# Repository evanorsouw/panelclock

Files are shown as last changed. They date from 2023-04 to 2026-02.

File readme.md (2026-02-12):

# 1 Introduction

This project was the result of wanting to do something with those 64x64 RGB panels you see so often. 
The HUB75 interface that they use requires constant updating at a speed of (max) 30MHz.
I saw very clever solutions using Arduino and ESP boards but they lacked the ability to refresh
at a high enough frequency or at 8 bit color depth. I have always wanted to do something with an FPGA
and this is my first projects integrating the ICE40HX4K FPGA chip into a design.

Since I like clocks (as so many people) in all their shapes I decided create a clock from it.

> _This repository contains all files for the hardware (Kicad), FPGA (VHDL via IceCUBE2), software (C++/FreeRTOS/PlatformIO) and the mechanical stl files (design was made from Fusion360 but these are not in this archive).  
However much more documentation is needed not only for others, but also for myself as a reference later on._

It clock comes in 2 flavors, as a double panel in 128x64 landscape or portrait mode and as a single 64x64 panel.

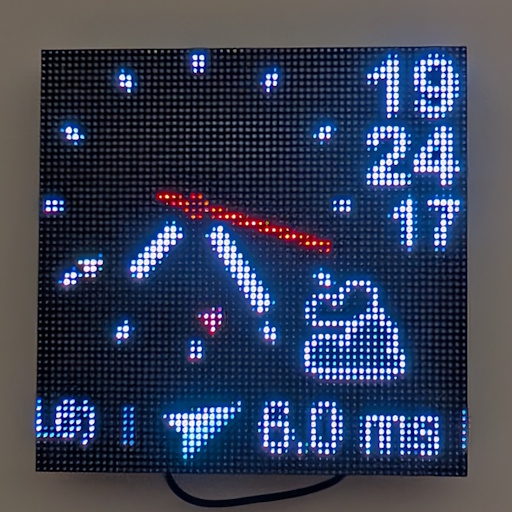
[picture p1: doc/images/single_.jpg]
single

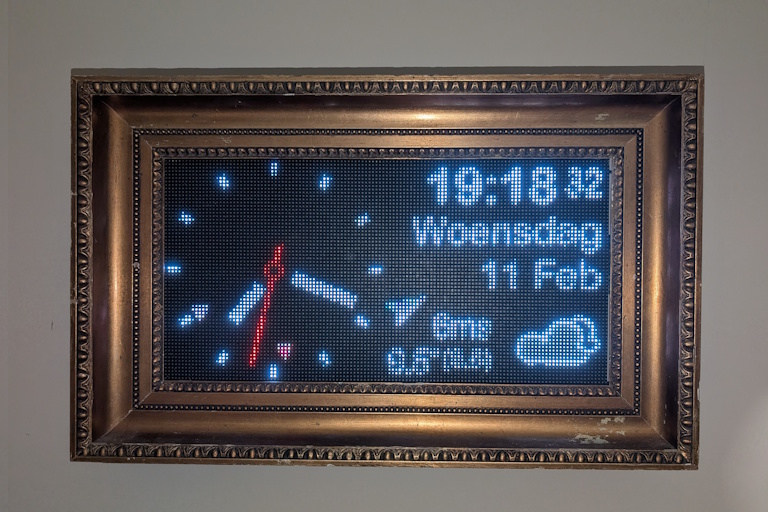
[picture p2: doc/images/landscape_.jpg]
landscape

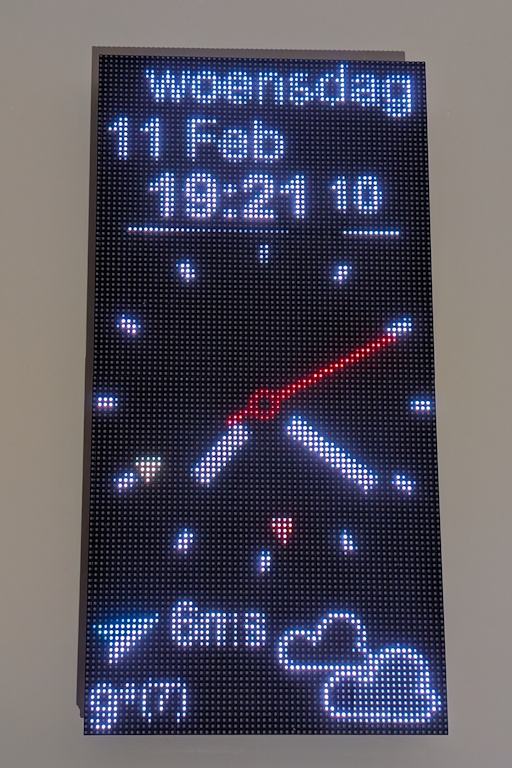
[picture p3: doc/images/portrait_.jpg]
portrait


# 1.1 History

The initial idea began somewhere 2019 with the purchase of a MAX1000 FPGA board. For this I created a small breakout board to 2 HUB75 connectors. The FPGA was used to do 25Hz rendering at 8bit color depth. The USB connector on the [MAX1000 board](https://duckduckgo.com/?t=ffab&q=google+max1000+trenz&ia=web) was used to push screen updates from the Linux system to the FPGA. The software was C# that I developed and tested on Windows in a simulation and run on Linux afterwards. This setup worked ok but required an external PC (NUC) running linux. You can still find this code in the `old` directory.

I wanted a compact stand-alone setup so in 2024 I started on designing a standalone system. Since at that time the bare MAX10 chip was not easily for sale for searching for an alternative I ran into the ICE40 FPGA. Less capable but more than enough for my purpose. Only real drawback was that internal FPGA memory was far less resulting in the need to add some external static RAM. 

Software wise there was a lot of trial-and-erroring and a lot of hurdles to get over. At the end it all worked nicely but it lacked unittests and the code is quite messy at places. Specifically getting the graphics rendering up to speed was challenging. Running bare metal, the very simple task of drawing 
antialised graphics took months to complete. The solution here was to have the ability to draw an antialised triangle and use that as basis for the rest. Text drawing was done using the brilliant [libschrift](https://github.com/tomolt/libschrift) library that allows me to render TTF fonts.

So in the end, now I know what I want and need I should rewrite much of the software and structurally add unittest...

# 2 Hardware

The hardware used in this project is relatively simple, with an ESP32 as main controller running the clock software and continuously pushing newly rendered images to the FPGA.
An ICE40 FPGA is used to refresh the images on 2 HUB75 connected displays.
Other than these 2 main components, the is a static 256KB RAM chip where the FPGA stores the received images (24KB each) for displaying, a simple USB based powersupply for 3v3 and 1v8, the well known CH340 chip for programming and downloading. There is also a MAX983657 amplifier on there but software wise it is not used yet. Most parts of this schematic are from standard application notes.

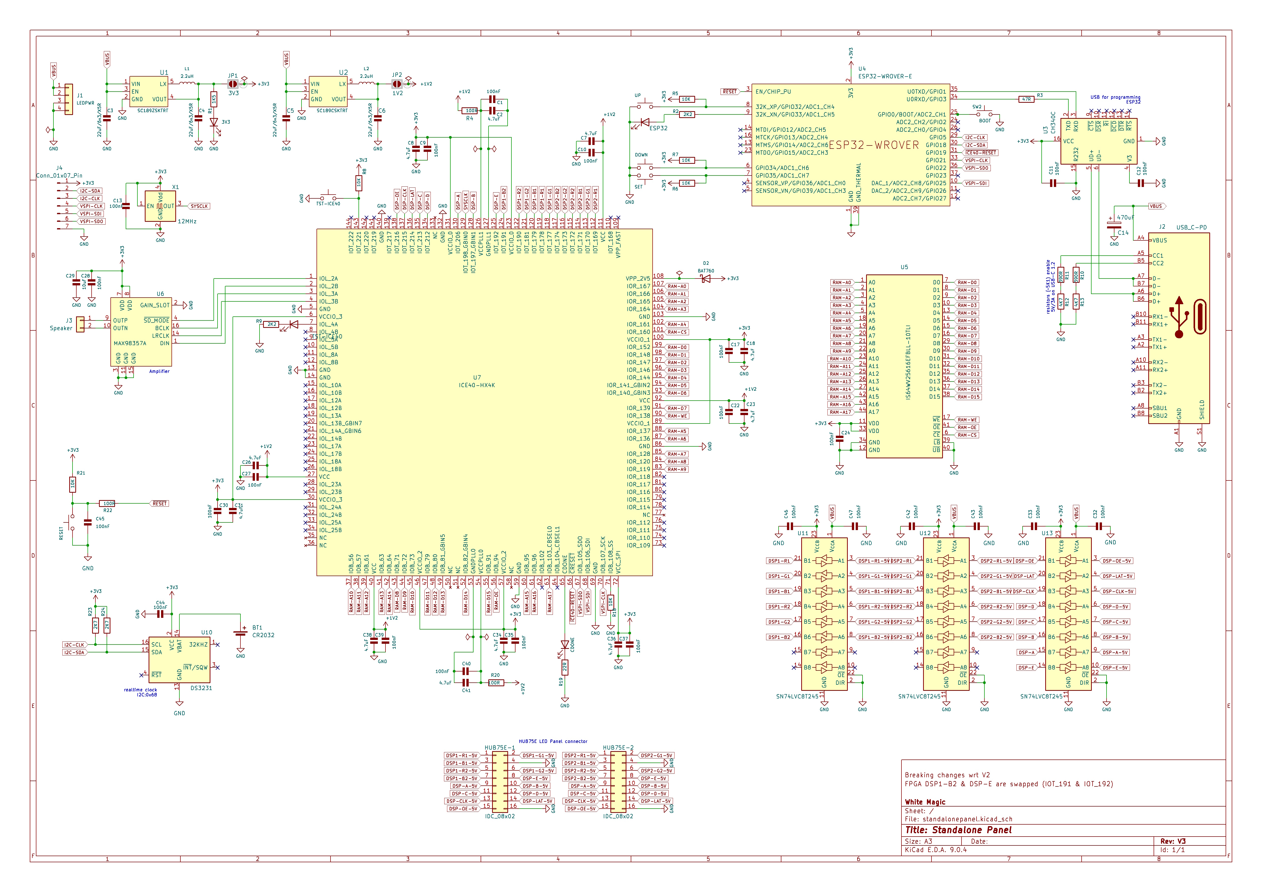
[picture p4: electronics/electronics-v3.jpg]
schematic


 The assembled 2-layer PCB looks like this; 
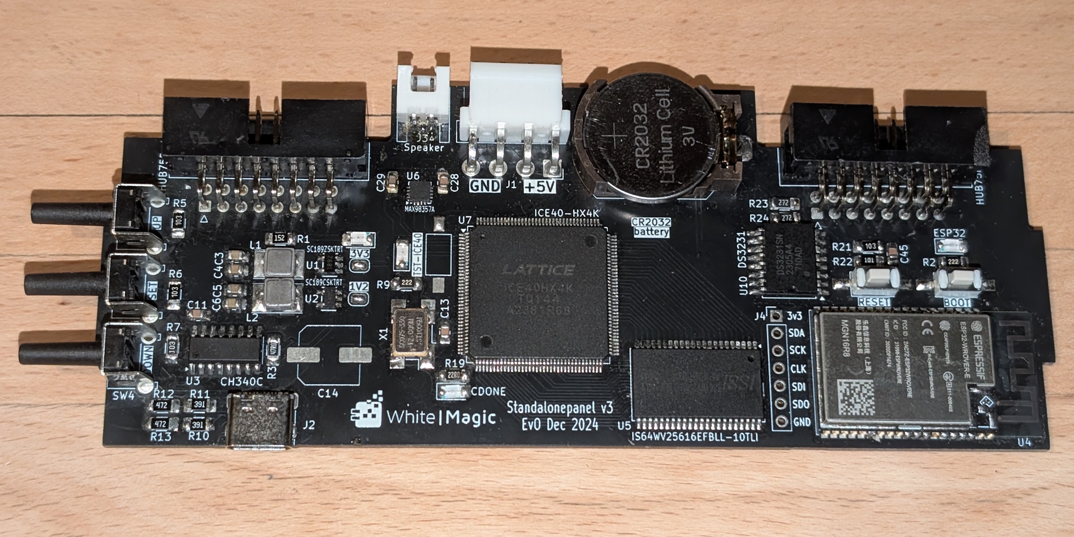
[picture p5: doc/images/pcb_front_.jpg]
pcb_front

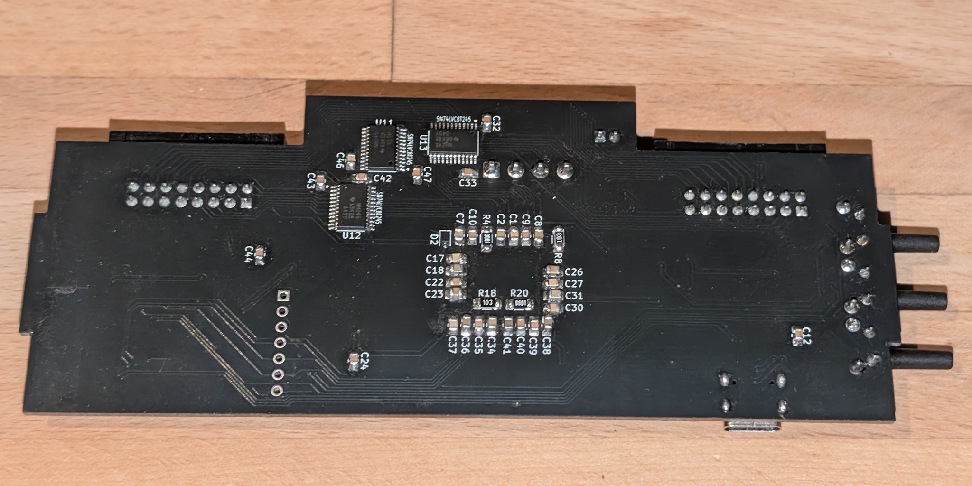
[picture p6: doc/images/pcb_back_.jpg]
pcb_back


# 3 Software

The software for the FPGA is VHDL compiled with the free (for personal use) [ICECube2 software](https://www.latticesemi.com/iCEcube2) from Lattice. 

The software for the ESP32 is developed using VisualCode and PlatformIO using FreeRTOS. The FPGA is configured via the ESP32 at startup via SPI. The ESP32 is setup to use A/B bootmode. When the software runs it will periodically (daily, weekly, monthly) check a configurable website if new software is available. If new software is found, it is installed and run. A special button combo during boot will revert the system back it fails.

The application uses 2 bitmaps that I toggle between. While 1 bitmap is being rendered, the other is sent to the FPGA. Since the ESP32 has 2 cores I typially use 1 core for rendering and the other for transferring the data. Some additional tasks run periodically like syncing with NTP and retrieving weather info.

The system has 3 buttons, `up`,`down` and `select` that are used for configuring the system. There are a number of configurable items for Wifi, NTP server, timezone etc. For weather information, [openweather](https://openweathermap.org/api) is used which requires you to request a free API key. This key also needs to be entered here together with your location. GUI-wise there is not much to configure the display is fixed but does display a variety of periodic animations, 5-minutes tick animations, expanding circles, game of life. 

A [usermanual](doc/usermanual.md) is found here.

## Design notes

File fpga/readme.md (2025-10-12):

# Programming the ICE40.

## Using my own Flash Programmer

mode com12 baud=115200 data=8 dtr=off stop=1 parity=n rts=off
copy /b ice40_Implmnt\sbt\outputs\bitmap\toplevel_bitmap.bin \\.\com12

## using Olimes 32u4 board;
-----------------------

1) have a Olimex 32U4 board programmed and connected via comport.
   determine comport (must be <10). if higher, then use device manager to change the comport
2) have the iCE40HX8K0-EVB board connected via 16pin flatcable.
   and powered via external jack to 5V.
4) from cmd prompt:
   winiceprog.exe -ICOMX -t
   => Manufacturer ID: 0x1C / Device ID: 0x7015
   this is the indication that the ICE40 board is found.
5) winiceprog -ICOM2 -v <binfile>
e.g.: WinICEProg.exe -ICOM2 -v ice40\ice40_Implmnt\sbt\outputs\bitmap\toplevel_bitmap.bin

Add to FPGA code:

- setcolor(r,g,b)
0x03,<R>,<G>,<B>

- setpixel(x,y,alpha) - use current color and blend pixel at x,y with existing pixel using <alpha>
0b10aaaaaa,<x>,<y>

- setnextpixel(alpha) - use current color and last position (x+1,y) and blend existing pixel using alpha then update current position to (x+1,y)
0b11aaaaaa 

the FPGA must get ability to read an RGB pixel value back from memory.
- writing a pixel takes 8 writes (each RGB bit need 1 read)
- reading a pixel also takes 8 writes

the alpha pixel blend must:
- read 24 pixel from memory 
- merge color using 6 bit alpha value:
  - calculate the color value for each RGB channel in the pixel:
    - clip(old * (63-alpha) + new * alpha, 255)
- write 24 pixel back to memory

performance:
- each read/write of a set of RGB pixels takes 2 clock cycles
- given 8 reads and 8 write leaves requires 16*x = 32 clock cycles.
- at 60MHz this leaves an ideal bandwith of ~1.877 million pixels, or 228 full 128x64 screens

using above techniques we can render a screen that has say 30% filling:
- worst case: 128 * 64 * 30% * 3 (setpixel) = 7372 bytes (@115200 baud = 0.64 sec)
- with 90% scanlines: (128 * 64 * 0.3) * 10% * 3 + (128 * 64 * 0.3) * 90% * 1 = 2949 (@115200 baud = 0.256 sec)

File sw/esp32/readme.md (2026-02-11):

# Board config

Because I used a ESP32-WROVER-E 16Mb (and with PSRAM) module on a custom PCB, I created a custom board configuration.
I copied an existing board file using a wrover module and modified it.

This board configuration, named `standalone-panel.json` is stored in the `boards`  directory of the project.

From the `platform.ini` you can refer to it by using the filename without json extension.

There were the links I used:
- <https://docs.platformio.org/en/stable/platforms/creating_board.html>
- <https://docs.platformio.org/en/latest/platforms/espressif32.html>

# Storing FPGA bitstream on ESP32 filesystem

SPIFFS is the concept used to stored data file in ESP32 flash memory. 
The ESP32-WROVER-E has 16MB of flash. you have to create a custom partition table to set space aside for the filesystem.

The gist is as follows:
- create custom partition table, e.g. `partitions.csv` and store it in the root of the project.
- copy the contents of an existing partition file and add the following line:
  - `storage,  data, spiffs,  ,        2M` to reserve 2Mb for the data partition.
- in `platform.ini` add an entry `board_build.partitions = partitions.csv`
- Add the following line to the file `CMakeFile.txt`:
  - `spiffs_create_partition_image(spiffs data)` 
- create the directory `data` in the root of yout project
- place the file you want to have available on the ESP32 in the `data` directory.
- run `menuconfig` and make the following change
  - in the partitions section select `Custom partition table CSV` and name it `partitions.csv`
- Now from platformio, select `Build Filesystem Image` and `Upload Filesystem Image`
  or  or even simpler, just use `Upload Filesystem Image`.

There were the links I used:
- https://community.platformio.org/t/unable-to-build-and-upload-spiffs-filesystem-image-with-framework-esp-idf/17820

# 2 Updating software

1. Build the software  
When all is fine, a firmware package `firmware.bin` is copied to the `sw\esp32\data` directory, along with a new manifest that contains a newer version number. 
2. Upload the files `firmware.bin` and `manifest.bin` to the web location that is monitored by the panelclock (default configuration: `whitemagic.it/panelclock`)
3. The panelclock will autmomatically pick it up next time it checks. By default the interval setting `Update` setting  is set to `weekly`. During development this can be changed to `minutely`.

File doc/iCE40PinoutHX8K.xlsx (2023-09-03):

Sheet: Pinout
iCE40 Pinout HX8K
Ball Function | Pin Type | Bank | (BG121) 121-Ball caBGA Ball Number | (CB132) 132-Ball csBGA Ball Number | (CM225) 225-Ball ucBGA Ball Number | (CT256) 256-Ball caBGA Ball Number
IOL_1A | DPIO | 3 | - | - | C2 | E4
IOL_1B | DPIO | 3 | - | - | B1 | B2
IOL_2A | DPIO | 3 | B1 | B1 | E4 | F5
IOL_2B | DPIO | 3 | B2 | C1 | D4 | B1
IOL_3A | DPIO | 3 | - | - | E3 | C1
IOL_3B | DPIO | 3 | - | - | C1 | C2
IOL_4A | DPIO | 3 | C4 | C3 | E5 | F4
IOL_4B | DPIO | 3 | C3 | D3 | D3 | D2
IOL_5A | DPIO | 3 | C2 | D1 | E6 | G5
IOL_5B | DPIO | 3 | C1 | E1 | D1 | D1
IOL_6A | DPIO | 3 | - | - | D2 | G4
IOL_6B | DPIO | 3 | - | - | E2 | E3
IOL_7A | DPIO | 3 | - | - | - | H5
IOL_7B | DPIO | 3 | - | - | - | E2
IOL_8A | DPIO | 3 | E1 | D4 | F5 | G3
IOL_8B | DPIO | 3 | D1 | E4 | F4 | F3
IOL_9A | DPIO | 3 | D2 | F4 | F3 | H3
IOL_9B | DPIO | 3 | D3 | F3 | F2 | F2
IOL_10A | DPIO | 3 | E2 | H4 | G2 | H6
IOL_10B | DPIO | 3 | E3 | G4 | F1 | F1
IOL_11A | DPIO | 3 | - | - | G3 | H4
IOL_11B | DPIO | 3 | - | - | G1 | G2
IOL_12A | DPIO | 3 | F1 | J3 | G5 | J4
IOL_12B | DPIO | 3 | F2 | J1 | H2 | H2
IOL_13A | DPIO | 3 | F4 | G3 | H6 | J5
IOL_13B_GBIN7 | GBIN | 3 | F3 | G1 | G4 | G1
IOL_14A_GBIN6 | GBIN | 3 | G1 | H1 | H5 | J3
IOL_14B | DPIO | 3 | G2 | H3 | H1 | H1
IOL_15A | DPIO | 3 | - | - | H3 | J2
IOL_15B | DPIO | 3 | - | - | J3 | J1
IOL_16A | DPIO | 3 | - | - | H4 | K1
IOL_16B | DPIO | 3 | - | - | J1 | K3
IOL_17A | DPIO | 3 | G3 | - | J5 | L4
IOL_17B | DPIO | 3 | H3 | - | J2 | L1
IOL_18A | DPIO | 3 | H1 | K3 | J4 | K4
IOL_18B | DPIO | 3 | H2 | K4 | K1 | M1
IOL_19A | DPIO | 3 | - | - | - | L6
IOL_19B | DPIO | 3 | - | - | - | L3
IOL_20A | DPIO | 3 | - | - | K3 | K5
IOL_20B | DPIO | 3 | - | - | L1 | M2
IOL_21A | DPIO | 3 | - | - | - | L7
IOL_21B | DPIO | 3 | - | - | - | N2
IOL_22A | DPIO | 3 | - | - | L3 | M6
IOL_22B | DPIO | 3 | - | - | M1 | M3
IOL_23A | DPIO | 3 | J1 | L1 | K5 | L5
IOL_23B | DPIO | 3 | K1 | M1 | M2 | N3
IOL_24A | DPIO | 3 | - | - | N2 | P1
IOL_24B | DPIO | 3 | - | - | M3 | M4
IOL_25A | DPIO | 3 | K2 | N1 | P1 | P2
IOL_25B | DPIO | 3 | J2 | P1 | K4 | M5
IOL_26A | DPIO | 3 | - | - | M4 | R1
IOL_26B | DPIO | 3 | - | - | L4 | N4
IOB_52 | PIO | 2 | - | - | N3 | N6
IOB_53 | PIO | 2 | - | - | P2 | T1
IOB_54 | PIO | 2 | - | - | N4 | P4
IOB_55 | PIO | 2 | - | - | R1 | R2
IOB_56 | PIO | 2 | L1 | P2 | L5 | N5
IOB_57 | PIO | 2 | J3 | - | R2 | T2
IOB_58 | PIO | 2 | - | - | - | P5
IOB_59 | PIO | 2 | - | P3 | - | R3
IOB_60 | PIO | 2 | - | - | M5 | R5
IOB_61 | PIO | 2 | L2 | - | R3 | T3
IOB_62 | PIO | 2 | - | - | L6 | -
IOB_63 | PIO | 2 | K3 | M4 | P4 | R4
IOB_64 | PIO | 2 | J4 | M3 | M6 | M7
IOB_65 | PIO | 2 | - | - | R4 | -
IOB_66 | PIO | 2 | - | - | - | N7
IOB_67 | PIO | 2 | - | - | N5 | P6
IOB_68 | PIO | 2 | - | - | - | M8
IOB_69 | PIO | 2 | - | - | P5 | T5
IOB_71 | PIO | 2 | L3 | L5 | R5 | R6
IOB_72 | PIO | 2 | L4 | L4 | L7 | P8
IOB_73 | PIO | 2 | K4 | P4 | N6 | T6
IOB_74 | PIO | 2 | - | P5 | - | L9
IOB_75 | PIO | 2 | - | - | M7 | T7
IOB_76 | PIO | 2 | - | - | - | T8
IOB_77 | PIO | 2 | - | M6 | P6 | P7
IOB_78 | PIO | 2 | J5 | L6 | M8 | N9
IOB_79 | PIO | 2 | K5 | M7 | R6 | T9
IOB_80 | PIO | 2 | - | - | - | M9
IOB_81_GBIN5 | GBIN | 2 | L5 | P7 | N7 | R9
IOB_82_GBIN4 | GBIN | 2 | K6 | P8 | L9 | K9
IOB_83 | PIO | 2 | - | - | P7 | P9
GNDPLL0 | GNDPLL | GNDPLL | L6 | L7 | N8 | N8
VCCPLL0 | VCCPLL | VCCPLL | J6 | M8 | L8 | L8
IOB_84 | PIO | 2 | - | - | P8 | R10
IOB_85 | PIO | 2 | - | - | M9 | L10
IOB_86 | PIO | 2 | J7 | - | N9 | P10
IOB_87 | PIO | 2 | H7 | L8 | K9 | N10
IOB_88 | PIO | 2 | - | - | R9 | T10
IOB_89 | PIO | 2 | K7 | P9 | L10 | T11
IOB_90 | PIO | 2 | - | - | P9 | -
IOB_91 | PIO | 2 | J8 | M9 | N10 | T15
IOB_92 | PIO | 2 | - | - | P10 | T14
IOB_93 | PIO | 2 | - | - | - | M11
IOB_94 | PIO | 2 | L7 | - | R10 | T13
IOB_96 | PIO | 2 | - | - | P11 | -
IOB_98 | PIO | 2 | - | - | R11 | N12
IOB_99 | PIO | 2 | - | - | - | L11
IOB_100 | PIO | 2 | - | - | P13 | T16
IOB_101 | PIO | 2 | - | - | - | M12
IOB_102 | PIO | 2 | - | - | R12 | R16
IOB_103_CBSEL0 | PIO | 2 | L8 | L9 | K11 | K11
IOB_104_CBSEL1 | PIO | 2 | H9 | P10 | P12 | P13
CDONE | CONFIG | 2 | K8 | M10 | M10 | M10
CRESET_B | CONFIG | 2 | L9 | L10 | N11 | N11
IOB_105_SDO | SPI | SPI | K9 | M11 | M11 | P12
IOB_106_SDI | SPI | SPI | J9 | P11 | L11 | P11
IOB_107_SCK | SPI | SPI | L10 | P12 | N12 | R11
IOB_108_SS | SPI | SPI | K10 | P13 | M12 | R12
VCC_SPI | SPI | SPI | L11 | L11 | N13 | N13
IOR_109 | PIO | 1 | - | M12 | R15 | R14
IOR_110 | PIO | 1 | - | P14 | P15 | R15
IOR_111 | PIO | 1 | - | L12 | R14 | P14
IOR_112 | PIO | 1 | - | N14 | P14 | P15
NC | NC | NC | - | M14 | N14 | N14
IOR_113 | PIO | 1 | - | - | M15 | P16
IOR_114 | PIO | 1 | J11 | L14 | L12 | M13
IOR_115 | PIO | 1 | K11 | K12 | M13 | M14
IOR_116 | PIO | 1 | H10 | K11 | K12 | L12
IOR_117 | PIO | 1 | J10 | K14 | K13 | N16
IOR_118 | PIO | 1 | G8 | J12 | J10 | L13
IOR_119 | PIO | 1 | H11 | J11 | L13 | L14
IOR_120 | PIO | 1 | G10 | H12 | J12 | K12
IOR_121 | PIO | 1 | - | - | L14 | M16
IOR_122 | PIO | 1 | - | - | - | J10
IOR_123 | PIO | 1 | - | - | M14 | M15
IOR_125 | PIO | 1 | - | - | K15 | -
IOR_126 | PIO | 1 | - | - | - | J11
IOR_127 | PIO | 1 | - | - | - | L16
IOR_128 | PIO | 1 | G9 | H11 | J11 | K13
IOR_129 | PIO | 1 | G11 | G12 | J13 | K14
IOR_130 | PIO | 1 | - | - | - | J15
IOR_131 | PIO | 1 | - | - | K14 | K15
IOR_133 | PIO | 1 | - | - | J15 | K16
IOR_134 | PIO | 1 | - | - | - | J14
IOR_135 | PIO | 1 | - | - | J14 | -
IOR_136 | PIO | 1 | F10 | G11 | H11 | J12
IOR_137 | PIO | 1 | F9 | F12 | H14 | J13
IOR_138 | PIO | 1 | - | - | H13 | J16
IOR_139 | PIO | 1 | - | - | - | H13
IOR_140_GBIN3 | GBIN | 1 | F11 | F14 | H12 | H11
IOR_141_GBIN2 | GBIN | 1 | E10 | G14 | G13 | H16
IOR_142 | PIO | 1 | - | - | - | H14
IOR_143 | PIO | 1 | - | - | G15 | G16
IOR_144 | PIO | 1 | E9 | F11 | G11 | H12
IOR_145 | PIO | 1 | - | - | G14 | G15
IOR_146 | PIO | 1 | E8 | E11 | G10 | G10
IOR_147 | PIO | 1 | D9 | E12 | F14 | F16
IOR_148 | PIO | 1 | E11 | E14 | G12 | G11
IOR_149 | PIO | 1 | - | - | F15 | F15
IOR_150 | PIO | 1 | - | - | - | G14
IOR_151 | PIO | 1 | - | - | F13 | E16
IOR_152 | PIO | 1 | D11 | D14 | F12 | G13
IOR_153 | PIO | 1 | - | - | E14 | D16
IOR_154 | PIO | 1 | D10 | C14 | F11 | G12
IOR_155 | PIO | 1 | - | - | D14 | F14
IOR_156 | PIO | 1 | - | - | - | F12
IOR_157 | PIO | 1 | - | - | - | D15
IOR_158 | PIO | 1 | - | - | - | F11
IOR_159 | PIO | 1 | - | - | D15 | -
IOR_160 | PIO | 1 | C11 | D12 | D13 | E14
IOR_161 | PIO | 1 | B11 | B14 | E13 | C16
IOR_162 | PIO | 1 | - | - | - | F13
IOR_165 | PIO | 1 | - | - | C14 | B16
IOR_166 | PIO | 1 | - | - | - | E13
IOR_167 | PIO | 1 | - | - | B15 | D14
VPP_2V5 | VPP | VPP | C10 | A14 | E12 | E12
VPP_FAST | VPP | VPP | B10 | A13 | D12 | D12
IOT_168 | PIO | 0 | A11 | - | B14 | C14
IOT_169 | PIO | 0 | - | - | A15 | B15
IOT_170 | PIO | 0 | A10 | A12 | C12 | D13
IOT_171 | PIO | 0 | - | - | C13 | B14
IOT_172 | PIO | 0 | C9 | C12 | E11 | C12
IOT_173 | PIO | 0 | - | - | - | E11
IOT_174 | PIO | 0 | B9 | C11 | D11 | C13
IOT_176 | PIO | 0 | - | - | B13 | A16
IOT_177 | PIO | 0 | B8 | D10 | E10 | A15
IOT_178 | PIO | 0 | A9 | D11 | D9 | B13
IOT_179 | PIO | 0 | C8 | A11 | E9 | E10
IOT_180 | PIO | 0 | - | - | B12 | C11
IOT_181 | PIO | 0 | D7 | A10 | D10 | D11
IOT_182 | PIO | 0 | - | - | C11 | B12
IOT_183 | PIO | 0 | - | - | - | B10
IOT_184 | PIO | 0 | - | - | A11 | B11
IOT_185 | PIO | 0 | - | - | B11 | C10
IOT_186 | PIO | 0 | - | C10 | - | A10
IOT_187 | PIO | 0 | - | - | B10 | A11
IOT_188 | PIO | 0 | - | D9 | - | -
IOT_189 | PIO | 0 | - | - | A10 | -
IOT_190 | PIO | 0 | A8 | C9 | F9 | D10
IOT_191 | PIO | 0 | C7 | - | C10 | C9
IOT_192 | PIO | 0 | A7 | - | B8 | E9
IOT_193 | PIO | 0 | - | - | C8 | D9
IOT_194 | PIO | 0 | - | - | A9 | A9
IOT_195 | PIO | 0 | - | - | B9 | -
VCCPLL1 | VCCPLL | VCCPLL | C6 | C8 | E8 | E8
GNDPLL1 | GNDPLL | GNDPLL | C5 | D8 | E7 | E7
IOT_196 | PIO | 0 | - | - | A8 | F9
IOT_197_GBIN1 | GBIN | 0 | B7 | A7 | C9 | C8
IOT_198_GBIN0 | GBIN | 0 | B6 | A6 | D8 | F7
IOT_199 | PIO | 0 | - | - | - | B9
IOT_200 | PIO | 0 | - | C7 | - | D8
IOT_201 | PIO | 0 | - | - | B7 | -
IOT_202 | PIO | 0 | - | D7 | - | -
IOT_203 | PIO | 0 | - | - | C6 | B8
IOT_205 | PIO | 0 | - | - | A7 | A7
IOT_206 | PIO | 0 | A6 | C6 | C7 | C7
IOT_207 | PIO | 0 | A5 | D6 | A6 | B7
IOT_208 | PIO | 0 | B5 | A5 | D7 | B6
IOT_209 | PIO | 0 | - | - | B6 | C6
IOT_210 | PIO | 0 | - | - | - | D7
IOT_211 | PIO | 0 | A4 | D5 | D6 | A6
IOT_212 | PIO | 0 | D5 | C5 | F7 | D6
IOT_213 | PIO | 0 | - | - | - | A5
IOT_214 | PIO | 0 | - | - | B5 | B5
IOT_215 | PIO | 0 | - | - | - | E6
IOT_216 | PIO | 0 | - | - | A5 | B4
GND | GND | GND | - | A9 | A12 | A12
IOT_218 | PIO | 0 | - | - | B4 | A2
GND | GND | GND | - | F1 | A4 | A4
IOT_219 | PIO | 0 | B4 | A4 | C5 | D5
IOT_220 | PIO | 0 | - | - | B3 | A1
GND | GND | GND | - | F7 | E15 | E15
IOT_221 | PIO | 0 | B3 | C4 | D5 | C5
GND | GND | GND | E5 | G7 | G7 | G7
IOT_222 | PIO | 0 | A2 | A3 | A2 | C4
GND | GND | GND | E6 | G8 | G8 | G8
IOT_223 | PIO | 0 | A3 | A2 | C4 | B3
GND | GND | GND | E7 | G9 | G9 | G9
GND | GND | GND | F5 | H6 | H7 | H7
GND | GND | GND | F6 | H7 | H8 | H8
IOT_224 | PIO | 0 | - | - | B2 | D4
GND | GND | GND | F7 | H8 | H9 | H9
IOT_225 | PIO | 0 | A1 | A1 | C3 | E5
GND | GND | GND | G5 | J14 | J7 | J7
IOT_226 | PIO | 0 | - | - | A1 | D3
GND | GND | GND | G6 | J8 | J8 | J8
IOT_227 | PIO | 0 | - | - | - | C3
GND | GND | GND | G7 | L3 | J9 | J9
GND | GND | GND | - | P6 | K2 | K2
GND | GND | GND | H5 | - | K7 | K7
GND | GND | GND | - | - | L15 | L15
GND | GND | GND | - | - | R7 | R7
GND | GND | GND | - | - | - | T12
GND | GND | GND | - | - | - | T4
VCC | VCC | VCC | - | F8 | A14 | A14
VCC | VCC | VCC | D8 | G6 | F10 | F10
VCC | VCC | VCC | D4 | H9 | F6 | F6
VCC | VCC | VCC | - | J4 | H15 | K10
VCC | VCC | VCC | H8 | J7 | K10 | K6
VCC | VCC | VCC | H4 | - | K6 | L2
VCC | VCC | VCC | - | - | L2 | -
VCC | VCC | VCC | - | - | R8 | -
VCCIO_0 | VCCIO | VCCIO | - | A8 | A13 | A13
VCCIO_0 | VCCIO | VCCIO | - | F6 | A3 | A3
VCCIO_0 | VCCIO | VCCIO | D6 | - | F8 | A8
VCCIO_0 | VCCIO | VCCIO | - | - | - | F8
VCCIO_1 | VCCIO | VCCIO | - | F9 | C15 | C15
VCCIO_1 | VCCIO | VCCIO | F8 | H14 | H10 | H10
VCCIO_1 | VCCIO | VCCIO | - | - | N15 | H15
VCCIO_1 | VCCIO | VCCIO | - | - | - | N15
VCCIO_2 | VCCIO | VCCIO | H6 | J9 | K8 | K8
VCCIO_2 | VCCIO | VCCIO | - | M5 | P3 | P3
VCCIO_2 | VCCIO | VCCIO | - | - | R13 | R13
VCCIO_2 | VCCIO | VCCIO | - | - | - | R8
VCCIO_3 | VCCIO | VCCIO | - | E3 | E1 | E1
VCCIO_3 | VCCIO | VCCIO | E4 | J6 | G6 | G6
VCCIO_3 | VCCIO | VCCIO | G4 | K1 | J6 | J6
VCCIO_3 | VCCIO | VCCIO | - | - | N1 | N1

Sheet: Revision History
Version | Date | Description
3.1 | 2017/02/05 | change name from "CM121" to "BG121" for "121-Ball caBGA"
3.0 | 2017/01/18 | add CM121(new 9x9 mm package ucBGA121),Revision "iCE40HX08.pkt 1.1"
2.1 | 2013-06-13 | Included package ordering code.
2.0 | 2013-03-13 | Updated table format to include all packages
1.1 | 10/3/2012 | Changed name from "CT256" to "256 ball caBGA"
1.0 | 2012-03-22 | Production Release Updated Notes in Pinout tab.
0.9 | 2011-09-01 | Preliminary

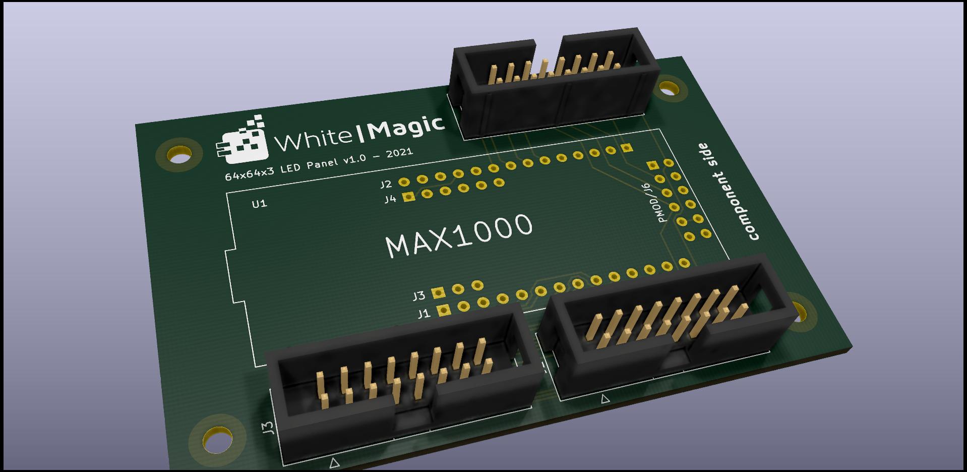
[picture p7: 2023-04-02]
electronics/kicad/max1000breakout/max1000breakout-v1.0.jpg

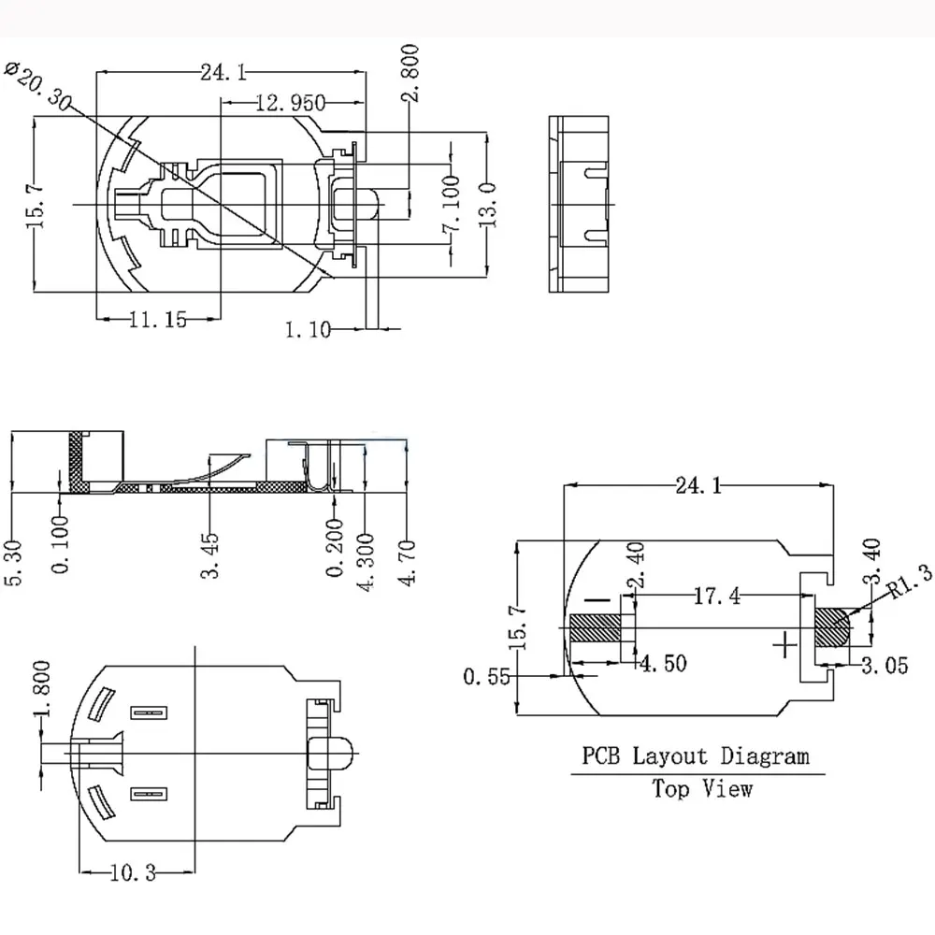
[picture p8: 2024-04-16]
doc/datasheet/batteryclip-2032.webp

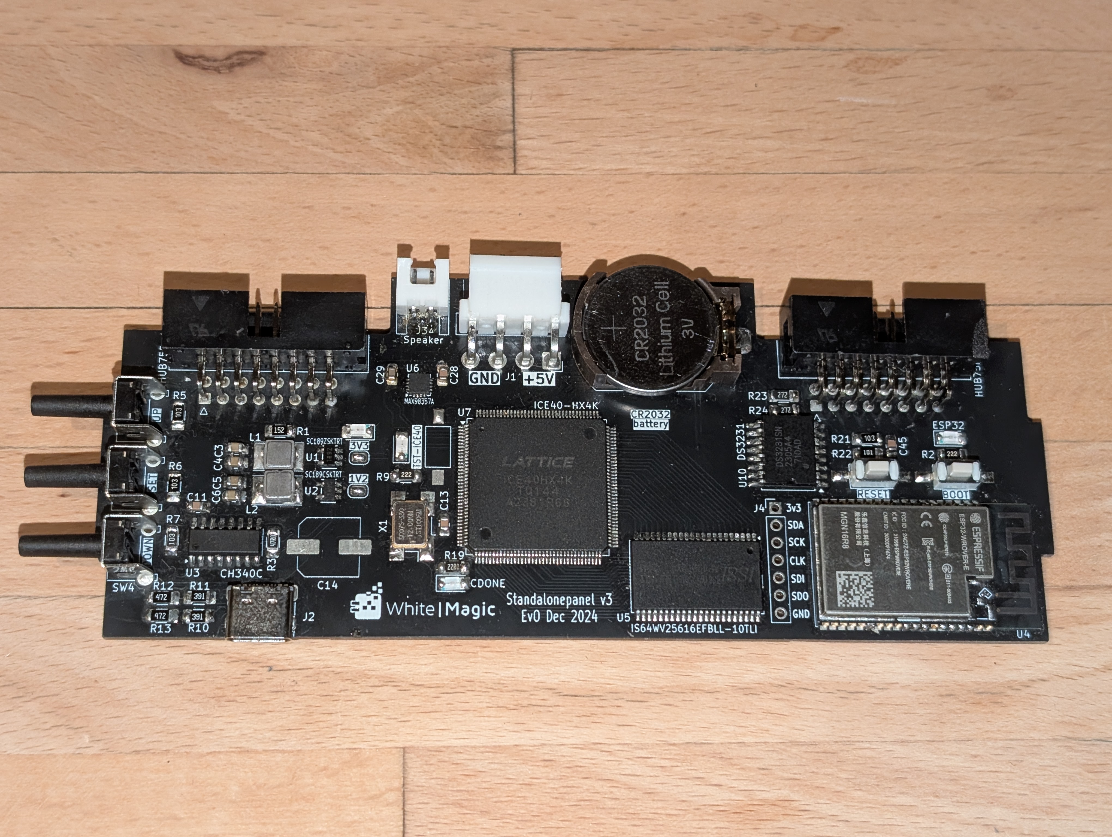
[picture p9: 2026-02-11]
doc/images/pcb_front.jpg

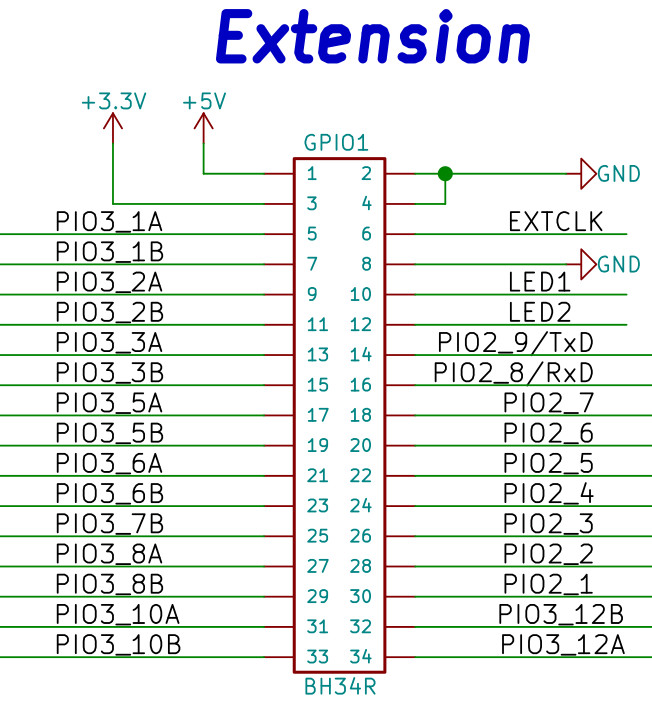
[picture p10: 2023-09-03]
doc/ICE40BUS.jpg

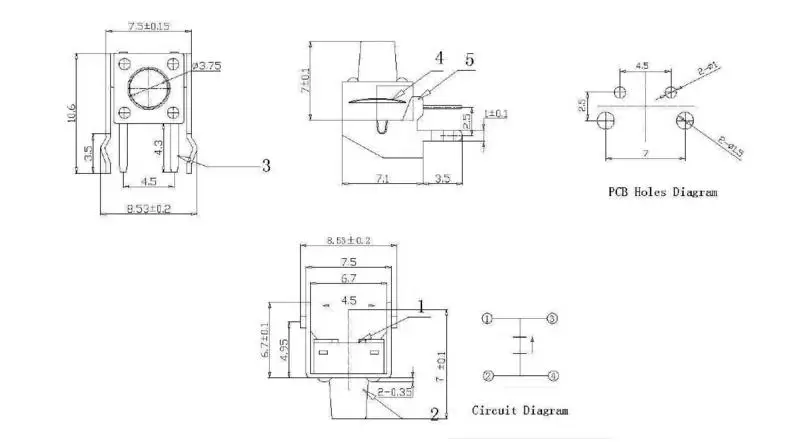
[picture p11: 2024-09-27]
doc/datasheet/100Pcs-Tact-Switch-6-6-9mm-Horizontal-with-Bracket-Tactile-Push-Button-Switches-6x6x9mm-Micro-Switch.jpg_.webp

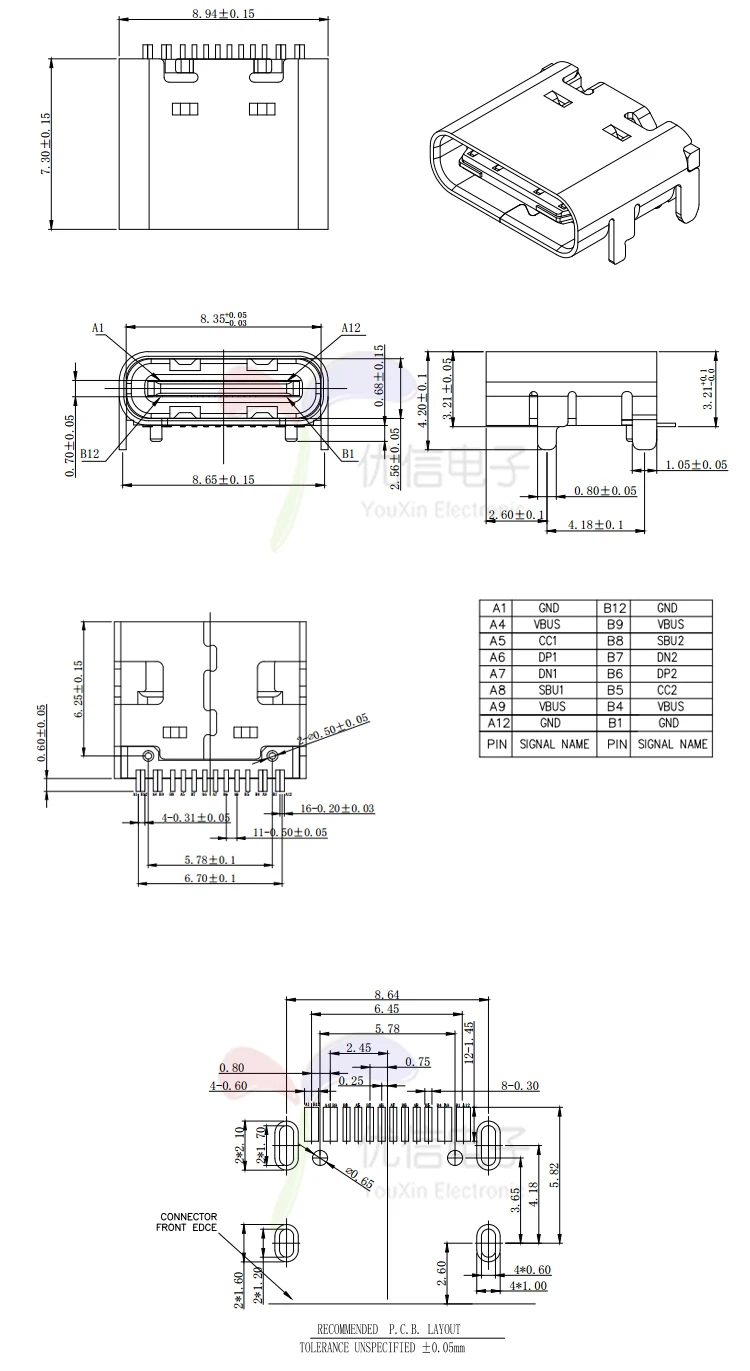
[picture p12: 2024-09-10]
doc/usb-c-connector-info.webp

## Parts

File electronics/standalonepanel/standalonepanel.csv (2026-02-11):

Source: | D:\projects\fpgaclock\electronics\kicad\standalonepanel\standalonepanel.kicad_sch
Date: | 25/02/2024 19:27:38
Tool: | Eeschema 7.0.9
Generator: | C:\Program Files\KiCad\7.0\bin\scripting\plugins/bom_csv_grouped_by_value_with_fp.py
Component Count: | 80
Ref | Qnty | Value | Cmp name | Footprint | Description | Vendor | DNP
C1, C9, C10, C11, C12, C13, C14, C15, C18, C20, C22, C24, C25, C27, C29, C31, C33, C34 | 18 | 100nF | C | Capacitor_SMD:C_0805_2012Metric_Pad1.18x1.45mm_HandSolder | Unpolarized capacitor
C2, C7, C8, C16, C19, C21, C26, C28, C30, C32, C35 | 11 | 4.7uF | C | Capacitor_SMD:C_0805_2012Metric_Pad1.18x1.45mm_HandSolder | Unpolarized capacitor
C3, C4, C5, C6 | 4 | 22uF/6v3/X5R | C | Capacitor_SMD:C_0805_2012Metric_Pad1.18x1.45mm_HandSolder | Unpolarized capacitor
C17 | 1 | 1uF | C | Capacitor_SMD:C_0805_2012Metric_Pad1.18x1.45mm_HandSolder | Unpolarized capacitor
C23 | 1 | 10uF | C | Capacitor_SMD:C_0805_2012Metric_Pad1.18x1.45mm_HandSolder | Unpolarized capacitor
D1, D2 | 2 | 1N5819WS | 1N5819WS | Diode_SMD:D_SOD-323_HandSoldering | 40V 600mV@1A 1A SOD-323 Schottky Barrier Diodes, SOD-323
DSP1, DSP2 | 2 | IDC_08x02 | Conn_02x08_Odd_Even | Connector_IDC:IDC-Header_2x08_P2.54mm_Vertical | Generic connector, double row, 02x08, odd/even pin numbering scheme (row 1 odd numbers, row 2 even numbers), script generated (kicad-library-utils/schlib/autogen/connector/)
F1 | 1 | 500mA | Fuse | 0_whitemagic:FUSEHOLDER 1808 | Fuse
J1 | 1 | USB-A | USB_A | Connector_USB:USB_A_Molex_67643_Horizontal | USB Type A connector
L1, L2 | 2 | 2.2uH | L | Inductor_SMD:L_Abracon_ASPI-0630LR | Inductor
LED1 | 1 | ESP32 | LED | LED_SMD:LED_1206_3216Metric_Pad1.42x1.75mm_HandSolder | Light emitting diode
LED2 | 1 | 3V3 | LED | LED_SMD:LED_1206_3216Metric_Pad1.42x1.75mm_HandSolder | Light emitting diode
LED3 | 1 | ICE40 | LED | LED_SMD:LED_1206_3216Metric_Pad1.42x1.75mm_HandSolder | Light emitting diode
LED4 | 1 | CDONE | LED | LED_SMD:LED_1206_3216Metric_Pad1.42x1.75mm_HandSolder | Light emitting diode
LS1 | 1 | Speaker | Speaker |  | Speaker
P1 | 1 | USB-C | USB_C | Connector_USB:USB_C_Receptacle_G-Switch_GT-USB-7010ASV | USB Type-C Plug connector
R1, R7, R9, R10, R11, R15 | 6 | 10K | R | Resistor_SMD:R_1206_3216Metric_Pad1.30x1.75mm_HandSolder | Resistor
R2, R12, R13 | 3 | 33R | R | Resistor_SMD:R_1206_3216Metric_Pad1.30x1.75mm_HandSolder | Resistor
R3 | 1 | 1K5 | R | Resistor_SMD:R_1206_3216Metric_Pad1.30x1.75mm_HandSolder | Resistor
R4, R14 | 2 | 100R | R | Resistor_SMD:R_1206_3216Metric_Pad1.30x1.75mm_HandSolder | Resistor
R5, R16 | 2 | 2K2 | R | Resistor_SMD:R_1206_3216Metric_Pad1.30x1.75mm_HandSolder | Resistor
R6 | 1 | 5K1 | R | Resistor_SMD:R_1206_3216Metric_Pad1.30x1.75mm_HandSolder | Resistor
R8 | 1 | 2K2 | R |  | Resistor
R17 | 1 | 100R | R |  | Resistor
SW1 | 1 | TST-ESP32 | SW_Push | Button_Switch_SMD:SW_SPST_FSMSM | Push button switch, generic, two pins
SW2 | 1 | BOOT | SW_Push | Button_Switch_SMD:SW_SPST_FSMSM | Push button switch, generic, two pins
SW3 | 1 | TST_ICE40 | SW_Push | Button_Switch_SMD:SW_SPST_FSMSM | Push button switch, generic, two pins
SW4 | 1 | RESET | SW_Push | Button_Switch_SMD:SW_SPST_FSMSM | Push button switch, generic, two pins
U1, U2 | 2 | SC189ZSKTRT | SC189ZSKTRT | SOT23-5-SC189_SEM
U3 | 1 | ESP32-WROOM-E | ESP32-WROOM-E | PCM_Espressif:ESP32-WROOM-32E | ESP32-WROOM-32E integrates ESP32-D0WD-V3, with higher stability and safety performance.
U4 | 1 | CH340C | CH340C | Package_SO:SOIC-16_3.9x9.9mm_P1.27mm | USB serial converter, UART, SOIC-16
U5 | 1 | SST25VF016B | SST25VF016B | Package_SO:SOIC-8_5.275x5.275mm_P1.27mm | 16-Mbit, 2.7 to 3.6V, SPI Flash Memory, SOIC-8
U6 | 1 | IS64WV25616EFBLL-10TLI | IS64WV25616EFBLL | Package_SO:TSOP-II-44_10.16x18.41mm_P0.8mm | 256K x 16 HIGH-SPEED CMOS STATIC RAM, 10ns, TSOP II-44
U7 | 1 | ICE40-HX4K-TQ144 | ICE40HX4K-TQ144
U8 | 1 | MAX3421E | MAX3421E | Package_QFP:PQFP-32_5x5mm_P0.5mm
U9 | 1 | MAX98357A | MAX98357A
X1 | 1 | 12MHz 5070 | TXC-7C | Oscillator:Oscillator_SMD_Fordahl_DFAS2-4Pin_7.3x5.1mm_HandSoldering | CMOS SMD Crystal Clock Oscillator, TXC

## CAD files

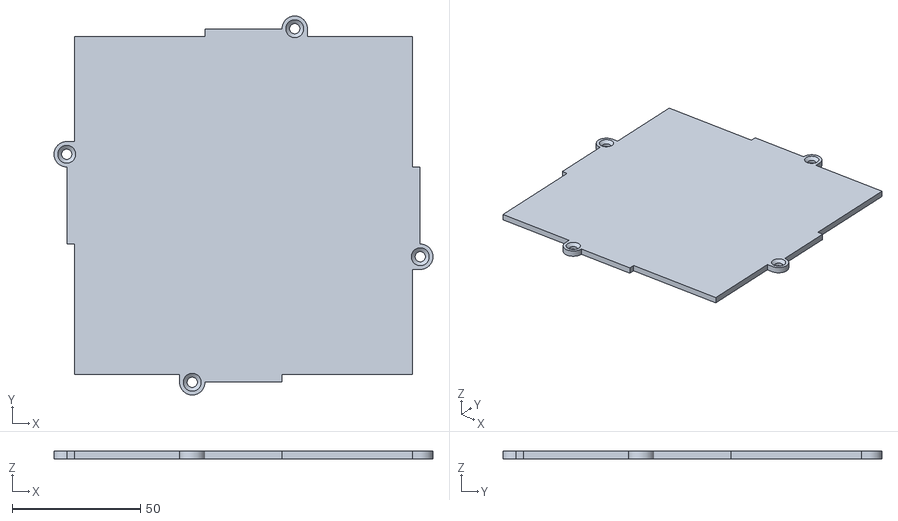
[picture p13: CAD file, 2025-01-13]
mechanics/initial/coverplate-no-lip.stl
147.9 x 147.9 x 3.00

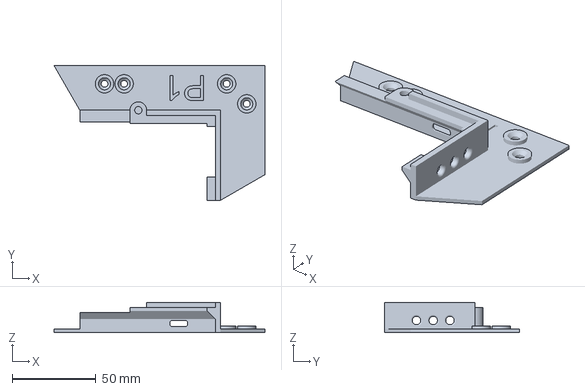
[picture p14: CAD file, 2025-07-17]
mechanics/type1-panel/panel-corner-with-holes.v33.3mf
126.1 x 80.6 x 18.0 mm

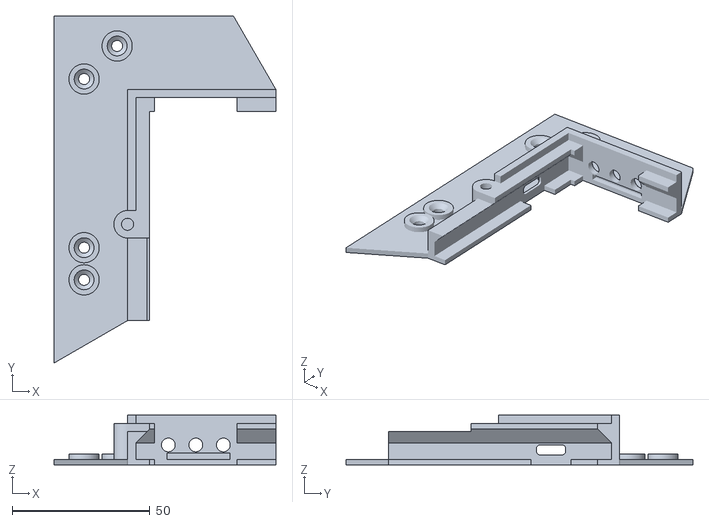
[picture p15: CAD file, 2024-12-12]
mechanics/initial/panel-corner-with-holes.v29.stl.stl
80.6 x 126.1 x 18.0

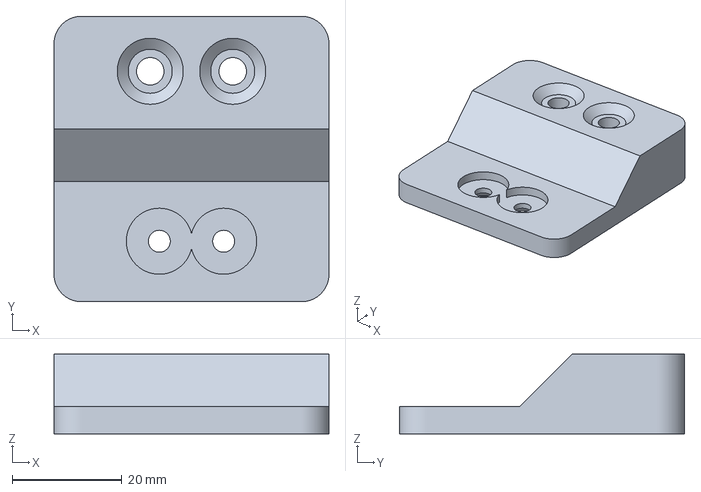
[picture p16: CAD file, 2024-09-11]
mechanics/initial/frame-clamp.3mf
50.0 x 51.9 x 14.5 mm

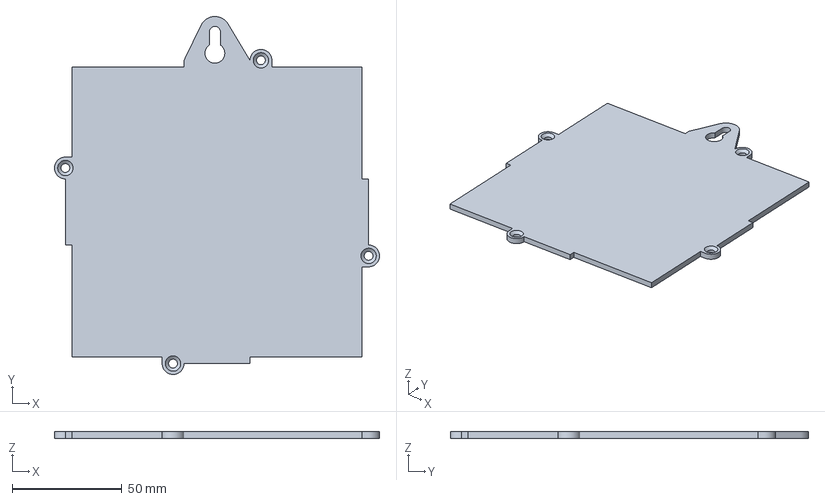
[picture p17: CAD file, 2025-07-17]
mechanics/type2-panel/coverplate-v17.3mf
147.9 x 162.9 x 3.00 mm

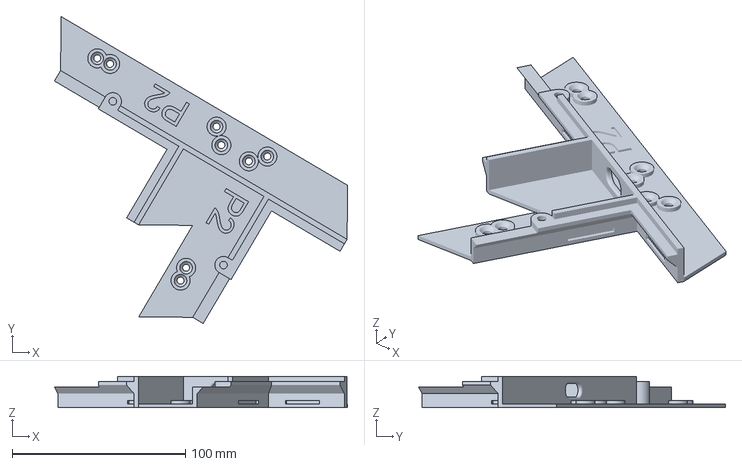
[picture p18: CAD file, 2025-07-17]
mechanics/type2-panel/panel-corner-link-v17.3mf
169.2 x 177.2 x 18.0 mm

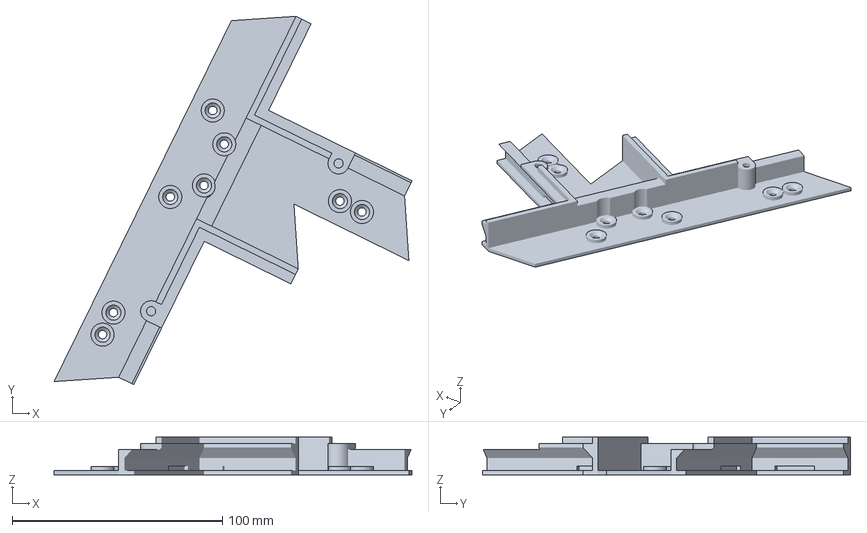
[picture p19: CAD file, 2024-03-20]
mechanics/initial/panel-corner-link.3mf
170.3 x 175.2 x 18.0 mm

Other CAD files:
mechanics/type2-panel/panel-corner-no-holes-v17.stl
mechanics/type2-panel/panel-corner-with-holes-v17.stl
mechanics/initial/panel-corner-no-holes.stl
mechanics/initial/coverplate-lip.3mf
mechanics/initial/coverplate-lip.stl
mechanics/initial/frame-clamp.stl
mechanics/initial/panel-corner-link.stl
mechanics/type1-panel/panel-corner-with-holes.v33.stl
mechanics/type2-panel/coverplate-v17.stl
mechanics/type2-panel/panel-corner-link-v17.stl

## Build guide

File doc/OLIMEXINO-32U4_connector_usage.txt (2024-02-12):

OLIMEX 32U4 REV.B Arduino board
-------------------------------
LEDs

PE6 - D7  - LED1    
PB5 - D9  - LED2
PD5 -     - Green LED  TxLED
PB0 - D17 - Yellow LED (Rx)

Buttons:
PE2   - HWB Button
Reset - Reset

Olimex Ice4040HX8K-EVB FPGA board
---------------------------

Male IDC connector
-------------------
UEXT Top-view (looking inside connector)

                            +-----+
        3v3 -           - 1 | o o | 2  Gnd           - Gnd
     D1/TxD -  IOB_99/RxD 3 | o o | 4  IOB_100/TxD   - D0/RxD
     D3/SCL -       CDONE 5   o o | 6  CRESET        - D2/SDA
   D14/MOSI           SDI 7 | o o | 8  SDO           - D16 MISO
    D15/SCK -         SCK 9 | o o | 10 SS_B          - D13/CS
                            +-----+

Olimex Ice4040HX8K-EVB board, GPIO connector (IDC)

-- view inside IDC connector (at back of panel)
Olimex board uses CT256 package
                                
                  GPIO1         +-----+        GPIO1
       IOL_1A/E4 - #5     R1  1 | o o | 2  G1   #7  - IOL_1B/B2
       IOL_2A/F5 - #9     B1  3 | o o | 4  GND  #2  - GND    
       IOL_2B/B1 - #11    R2  5 | o o | 6  G2   #13 - IOL_3A/C1
       IOL_3B/C2 - #15    B2  7   o o | 8  E    #17 - IOL_4A/F4
       IOL_4B/D2 - #19     A  9   o o | 10 B    #21 - IOL_5A/G5
       IOL_5B/D1 - #23     C 11 | o o | 12 D    #25 - IOL_6A/G4
       IOL_6B/E3 - #27   CLK 13 | o o | 14 LAT  #29 - IOL_7A/H5
       IOL_7B/E2 - #31    OE 15 | o o | 16 GND  #8  - GND       
                                +-----+

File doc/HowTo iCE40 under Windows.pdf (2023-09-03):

iCE40HX8K-EVB and iCE40HX1K HOW-TO GUIDE FOR WINDOWS

This document describes the different steps to write Verilog code and program the Olimex iCE40HX8K-EVB and iCE40HX1K-EVB boards under Windows environment. We also descrive the changes needed to operate the iCE40HX1K demo programs on the iCE40HX8K.

Written by Benoit BOUCHEZ (aka BEB) - (email : benoit -at- imodular-synth -dot- com) Document version 1 - August 2017

Even if we tried to make this document error free, you may find errors or missing informations. Don't hesitate to report any issue to us, so we can update the document.

Note that we can not provide support for the Olimex boards, iCECube sotware, various utilities, etc... so any question sent to the previous email will not be answered. Please use Olimex forum for any question related to the support.

Step 1 : Installation of iCEcube2

First of all, you will need to download two files from Lattice website :
- iCEcube2 installation program
- iCEcube2 license file

iCEcube2 is not open source and it requires a license to operate (the good thing is that you can get the license for free)

Before you can download anything from Lattice website, you will need to create a user account (it's free too). Click on "Register" on top bar of Lattice's website and follow all instructions. Note that you will need to click on the link provided in the confirmation email, so you need to use a valid email address.

Once you are registered on Lattice website, go to the following address :

http://www.latticesemi.com/Products/DesignSoftwareAndIP/FPGAandLDS/iCEcube2.aspx

Scroll down the whole page to reach the following table

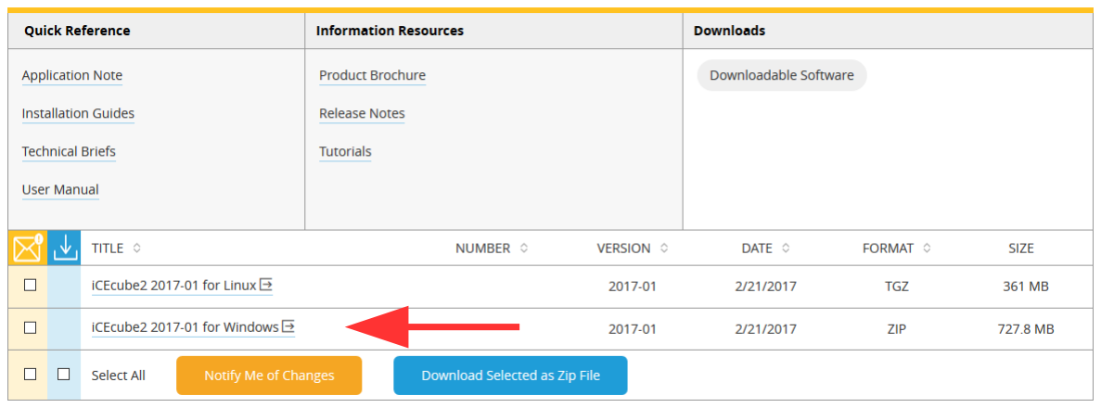
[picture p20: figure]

Click on the link "iCEcube2 xxxxx for Windows" (the numbers in the middle are the version code and may change). You will then reach the license agreement screen. Check the box under the license text and click "Download". The download of the installation program will then start (warning : the zip file is quite big – more than 700MB !)

Once the download is finished, you will have the installer ready.

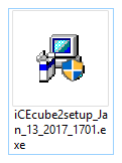
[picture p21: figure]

Note that Lattice indicates that iCEcube2 is designed to run under Windows XP and Windows 7. We use it under Windows 10 without any problems, so it can be assumed that it runs also correctly under Windows 8, but we did not test it.

Start the installer by double-clicking the icon and follow the instructions.

IMPORTANT : the iCEcube2 installer must be executed with administrator's rights.

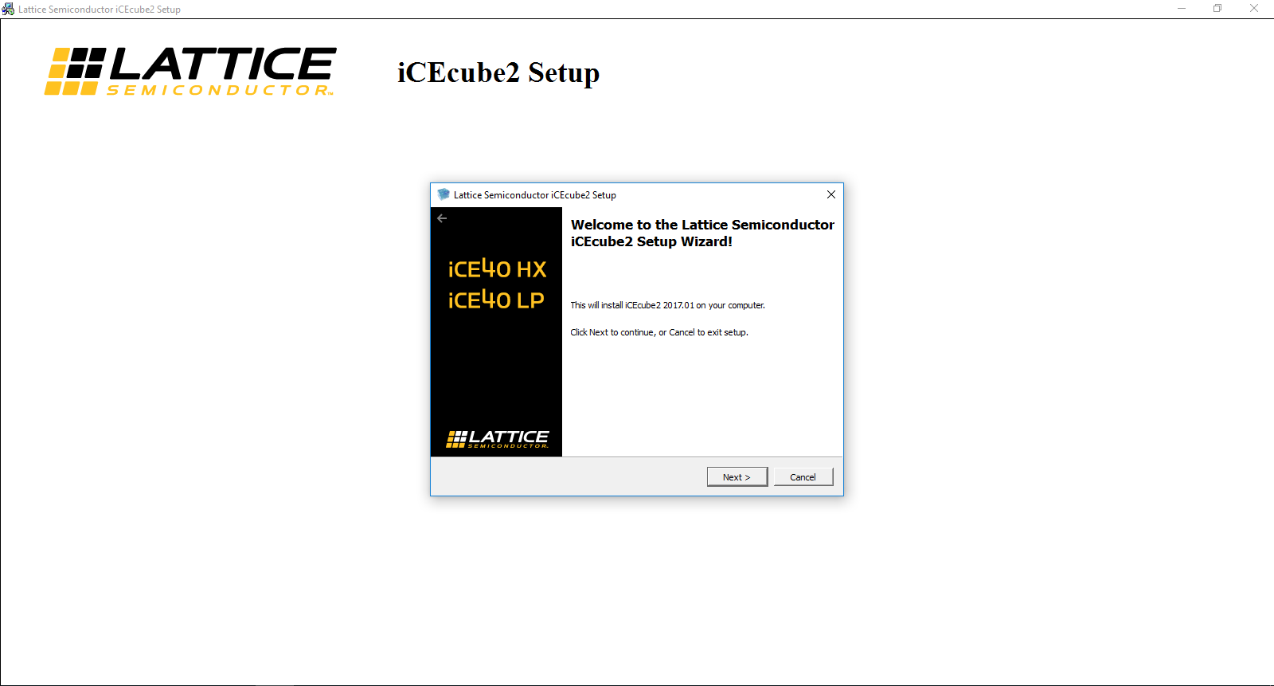
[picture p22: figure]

Once the installation is finished, you should have the iCEcube2 icon on your desktop window.

DO NOT START iCEcube2 for now! Since you don't have yet a license, the program will abort.

The license is physically attached to your computer and uses the network card MAC address to identify it. So the first thing to do is to retrieve the MAC address of the machine on which the software will run.

Press and hold the Windows key, and press the "R" key. In the window that opens, enter "cmd" (without the quotes) and press Enter. A shell window (sometimes called "MS-DOS window", but it is not a MS-DOS window at all...) will appear.

Type "ipconfig /all" command at the prompt

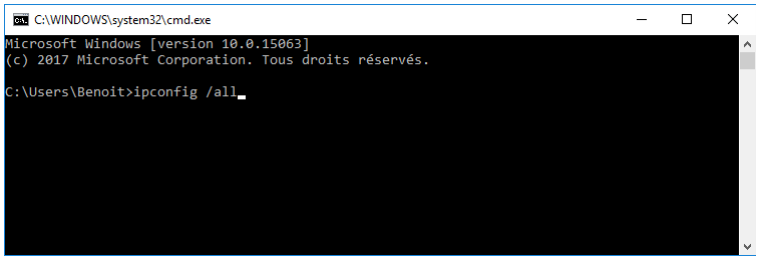
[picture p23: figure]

A list of all the network adapters available on your computer will appear. We recommend you to choose the MAC address of either the WiFi adapter or the physical network card.

It is not recommended to use virtual network cards addresses (from VMWare or Virtual Box for example) except if you know exactly what you. Since these addresses can be modified at any moment, they may invalidate the iCEcube2 license file (and you may loose countless hours to understand why the license file is not working anymore)

The MAC address is displayed on the line "Physical address", it is formed of 6 digits, separated by hyphens (sorry, my computer is in French... and yes I have hidden the three last digits of my address).

Go back to Lattice website and locate the "Request license" section on the iCEcube2 download page.

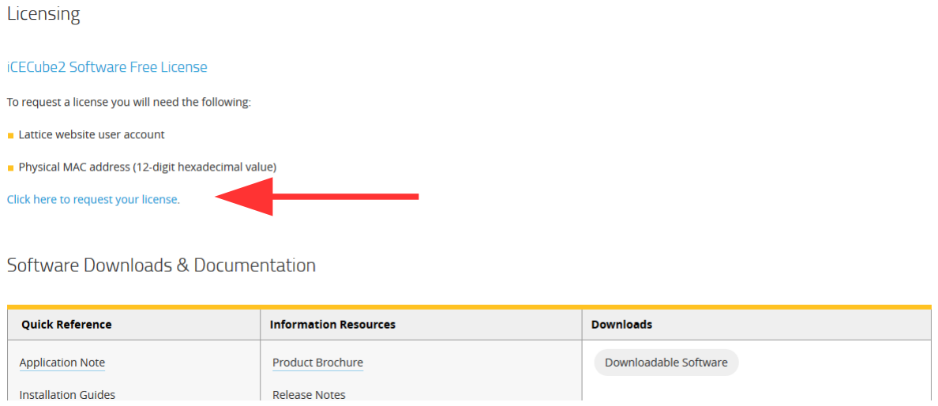
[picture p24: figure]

Click on "Click here to request your license". On the next page, check that you have provided your Lattice's account details and enter the MAC address you have retrieved on the computer.

Do not forget to check the "I am not an employee of Cadence, etc, etc..." and click on "Generate license"

The license file will be sent to the email address you gave in your Lattice account (that's why you need a valid email address). The file is called license.dat. Save it on your computer hard disk, we will need it very shortly.

Here we are finally, we can start iCEcube2... and get a funny window, just to be scared...

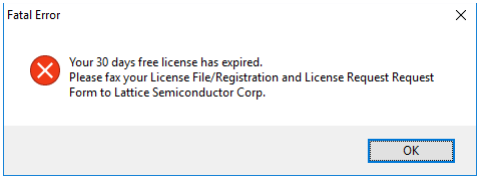
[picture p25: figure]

Don't worry, this window is displayed almost each time iCEcube2 is started, but it shall be ignored.

Click on the OK button to close the window, you will then get the following window :

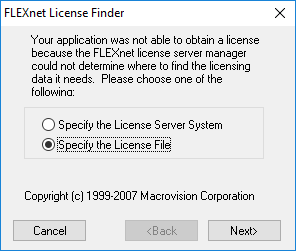
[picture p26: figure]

Choose "Specify the license file" and click on "Next"

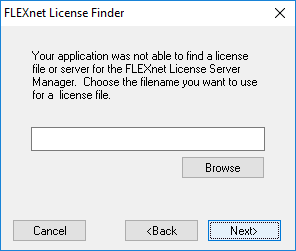
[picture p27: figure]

Click on "Browse" and locate the license you got by email just before. Once the license file

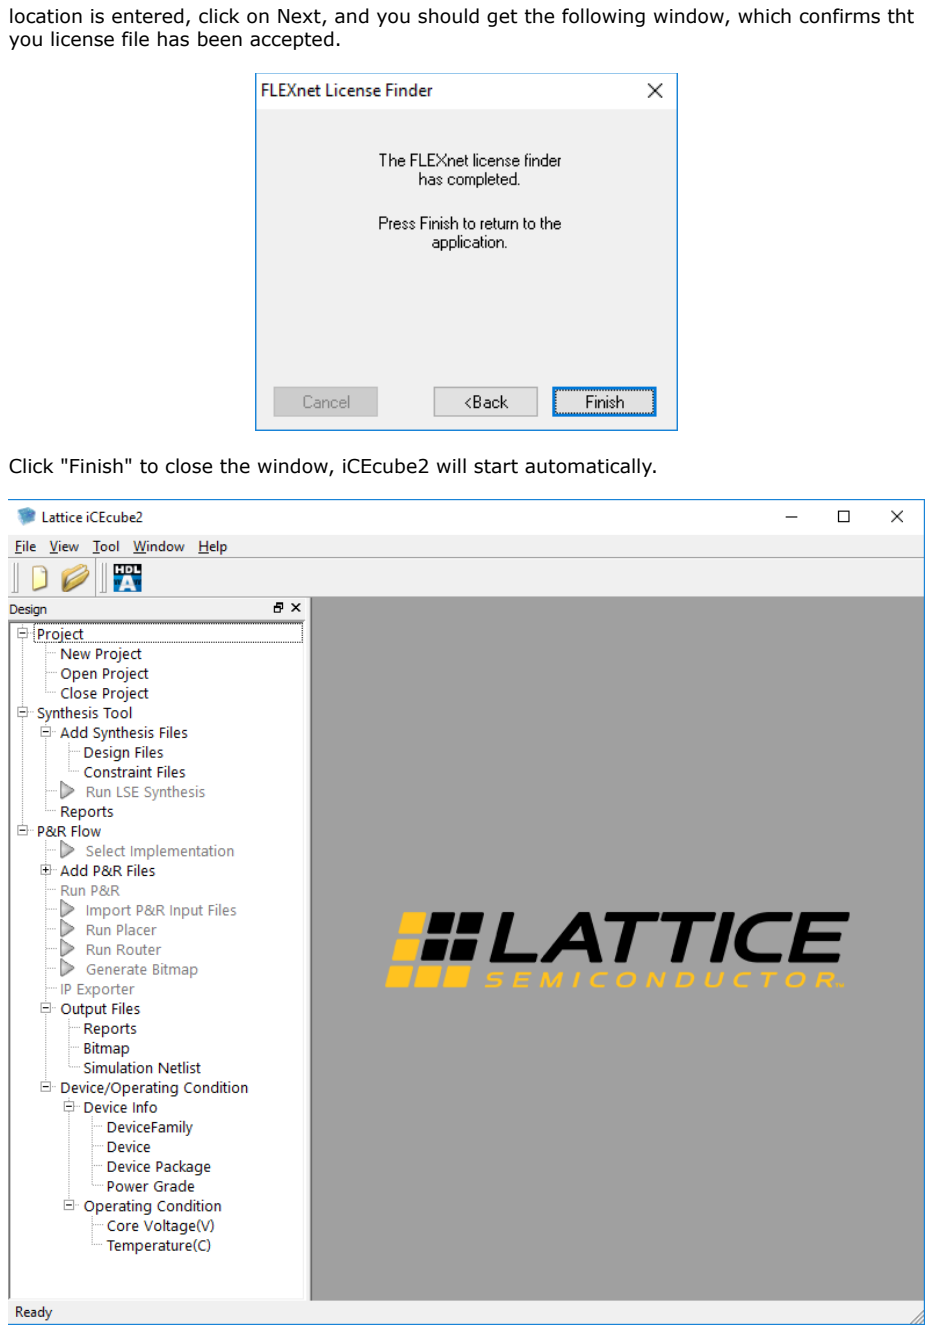
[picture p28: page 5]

location is entered, click on Next, and you should get the following window, which confirms tht you license file has been accepted.

Click "Finish" to close the window, iCEcube2 will start automatically.

Step 2 : Compilation of your first project

We will now see how to generate the FPGA bitmap (the file to load in the Flash on the Olimex iCE40HX8K or iCE40HX1K boards)

In iCEcube2, double click on "New project" on the left tree window (single click will not work!)

On the window that opens, enter :
- the name of the project you want to create (spaces are forbidden !)
- the location of the project on your hard disk.
- iCE40 for the device family

If you work with the iCE40HX8K-EVB board, select :
- H8K for the device
- CT256 for the package

If you work with the iCE40HX1K-EVB board, select :
- H1K for the device
- VQ100 for the package

Let all the other parameters as they are by default!

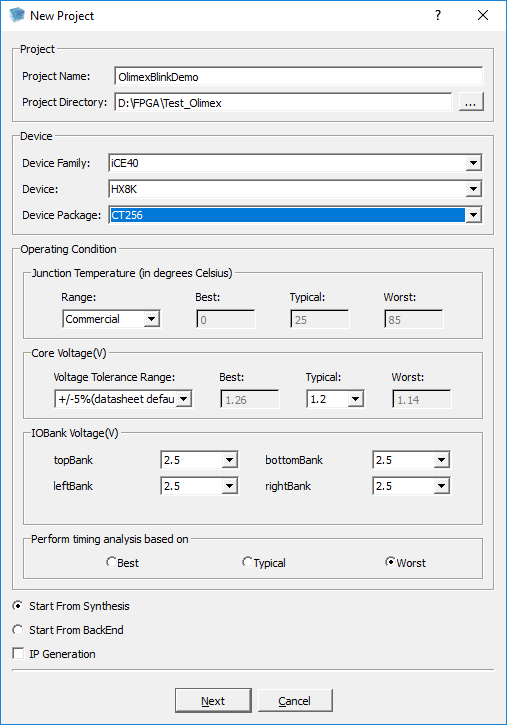
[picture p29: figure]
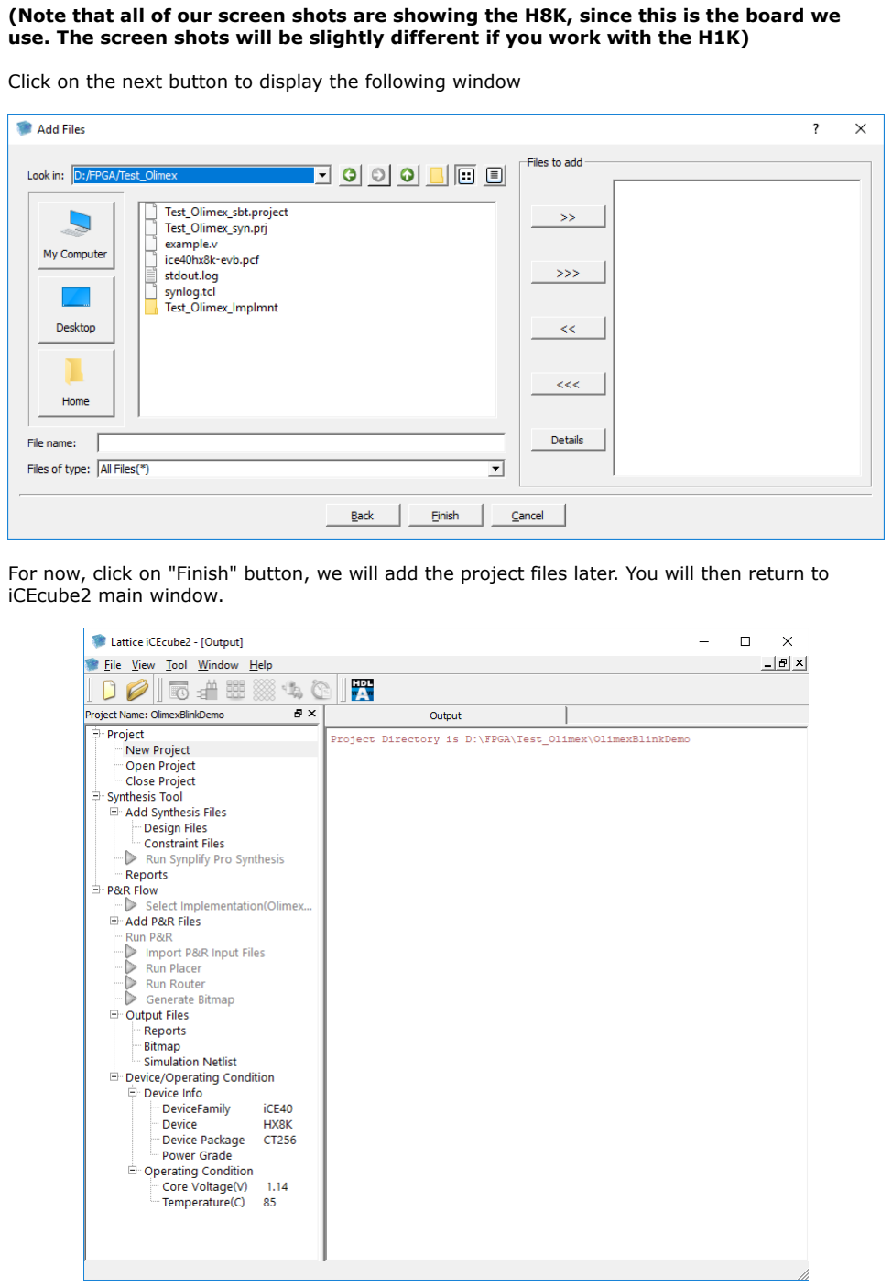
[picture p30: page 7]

(Note that all of our screen shots are showing the H8K, since this is the board we use. The screen shots will be slightly different if you work with the H1K)

Click on the next button to display the following window

For now, click on "Finish" button, we will add the project files later. You will then return to iCEcube2 main window.

Download the two following files from Olimex Github repository (use them even if you have a iCE40HX8K board) :

- example.v
- ice40hx1k-evb.pcf

These files are available here :

https://github.com/OLIMEX/iCE40HX1K-EVB/tree/master/demo/ice40hx1k-evb

Save the files in your project directory (the exact location does not really matter, but it's better to keep everything organized)

If you have a iCE40HX8K board, make a copy of the ice40hx1k-evb.pcf and save it under ice40hx8k-evb.pcf.

Back in iCEcube2, go to "Synthesis tool" / "Add synthesis files" and right-click on "Design files"

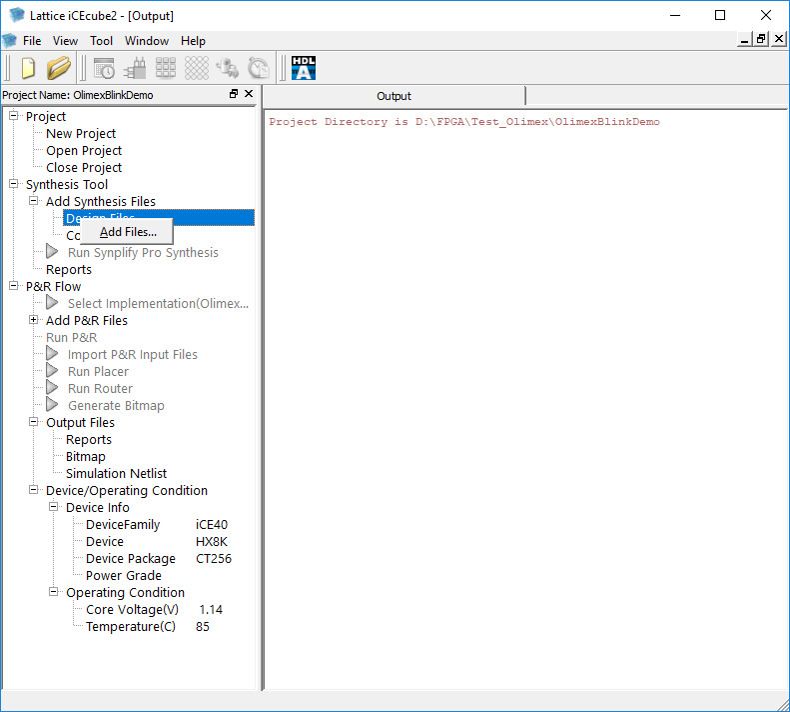
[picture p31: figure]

Click on "Add files" and locate the verilog source file you have downloaded just before. Click on the file name (example.v) and click on the ">>" button to make it appear in the right pane.

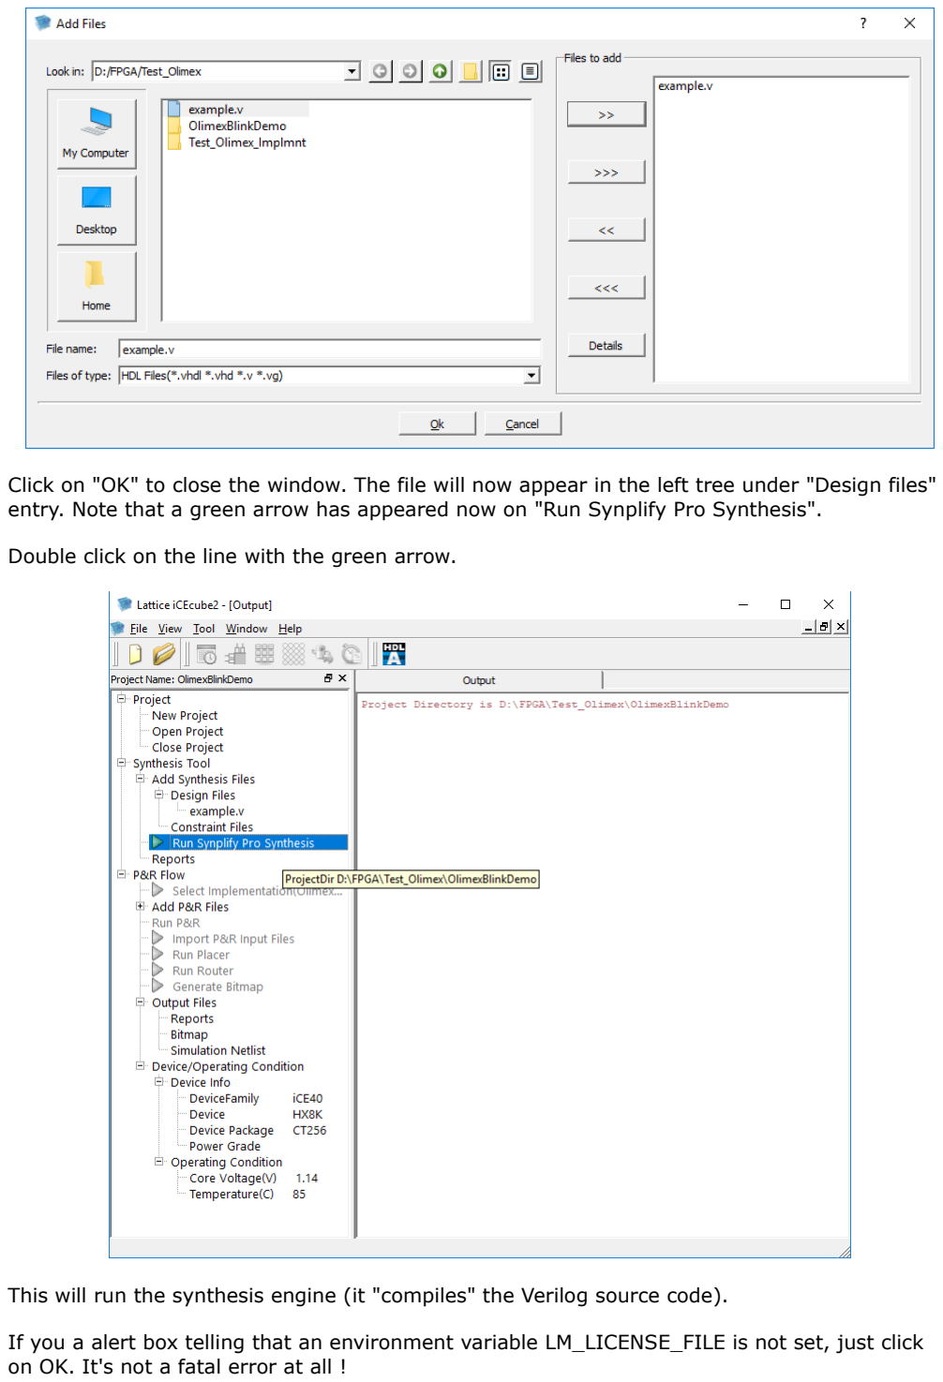
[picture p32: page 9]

Click on "OK" to close the window. The file will now appear in the left tree under "Design files" entry. Note that a green arrow has appeared now on "Run Synplify Pro Synthesis".

Double click on the line with the green arrow.

This will run the synthesis engine (it "compiles" the Verilog source code).

If you a alert box telling that an environment variable LM_LICENSE_FILE is not set, just click on OK. It's not a fatal error at all !

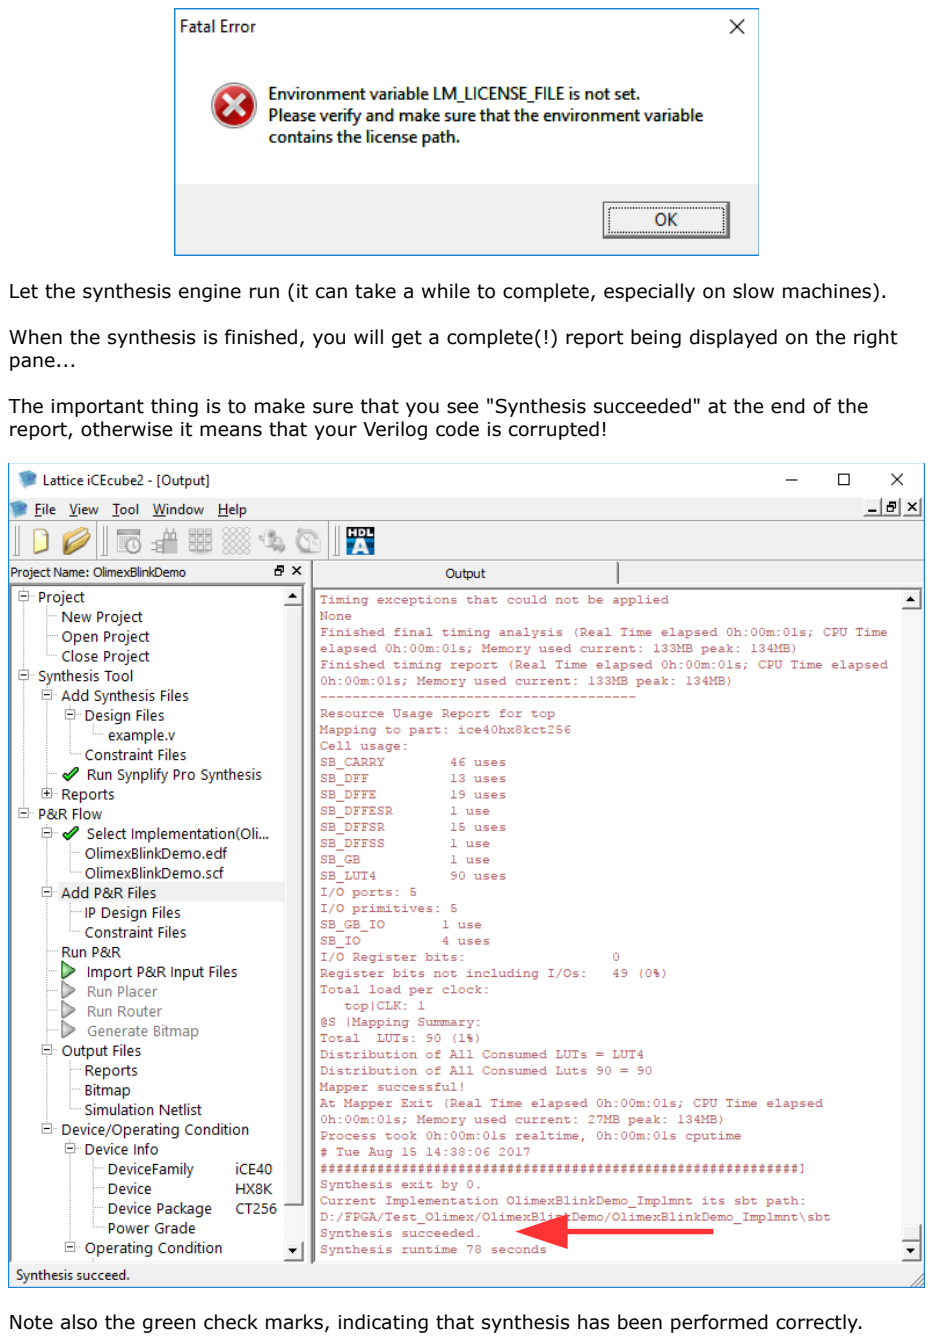
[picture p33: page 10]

Let the synthesis engine run (it can take a while to complete, especially on slow machines).

When the synthesis is finished, you will get a complete(!) report being displayed on the right pane...

The important thing is to make sure that you see "Synthesis succeeded" at the end of the report, otherwise it means that your Verilog code is corrupted!

Note also the green check marks, indicating that synthesis has been performed correctly.

Go now to "P&R flow" / "Add P&R Files" and right click on "Constraint files", then click on "Add files..."

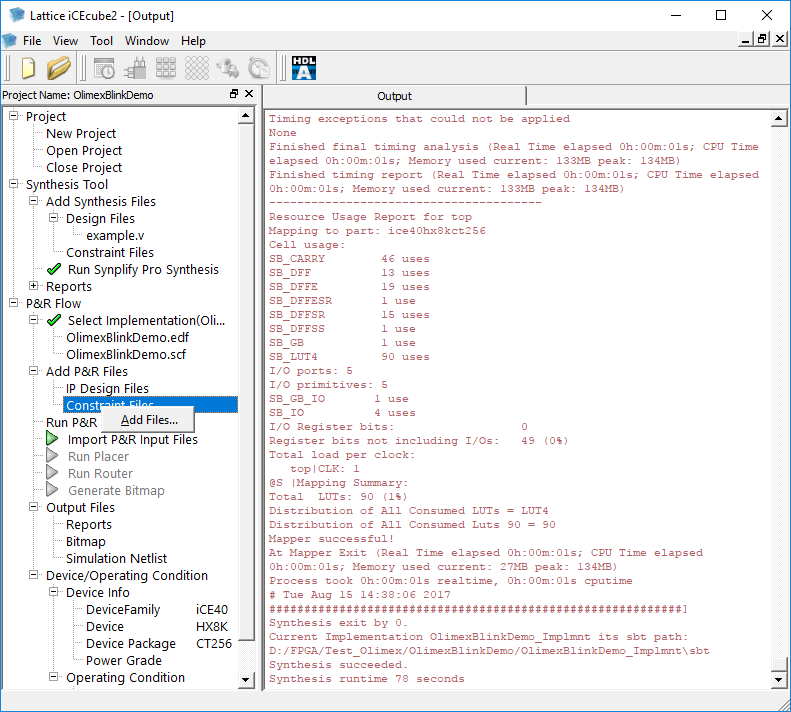
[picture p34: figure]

If you have the iCE40HX1K board, select the ice40hx1k-evb.pcf file.

If you have the iCE40HX8K board, select the ice40hx8k-evb.pcf file.

Click then on ">>" button to add the file in the project.

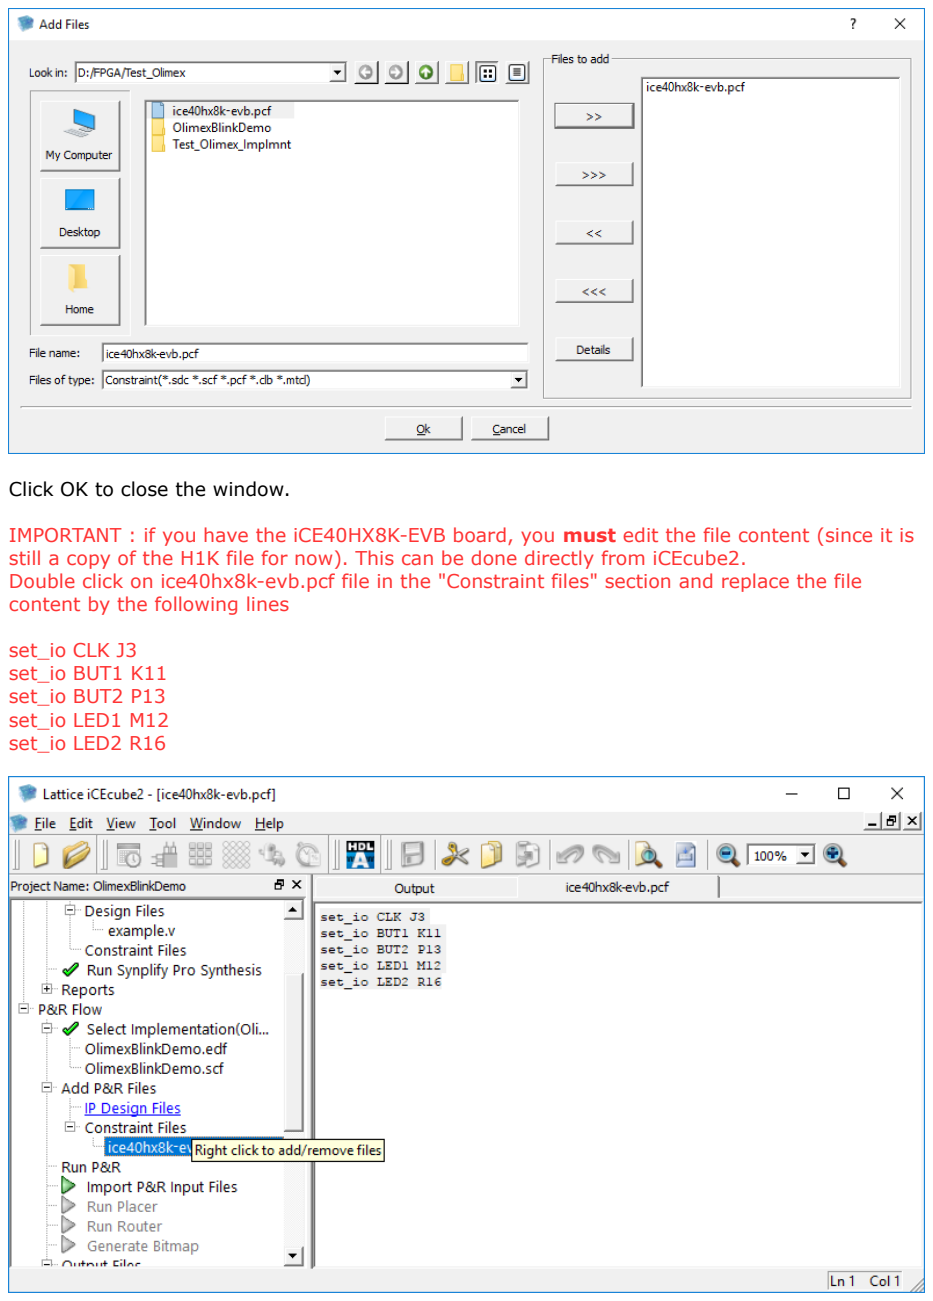
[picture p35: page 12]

Click OK to close the window.

IMPORTANT : if you have the iCE40HX8K-EVB board, you must edit the file content (since it is still a copy of the H1K file for now). This can be done directly from iCEcube2.
Double click on ice40hx8k-evb.pcf file in the "Constraint files" section and replace the file content by the following lines

set_io CLK J3
set_io BUT1 K11
set_io BUT2 P13
set_io LED1 M12
set_io LED2 R16

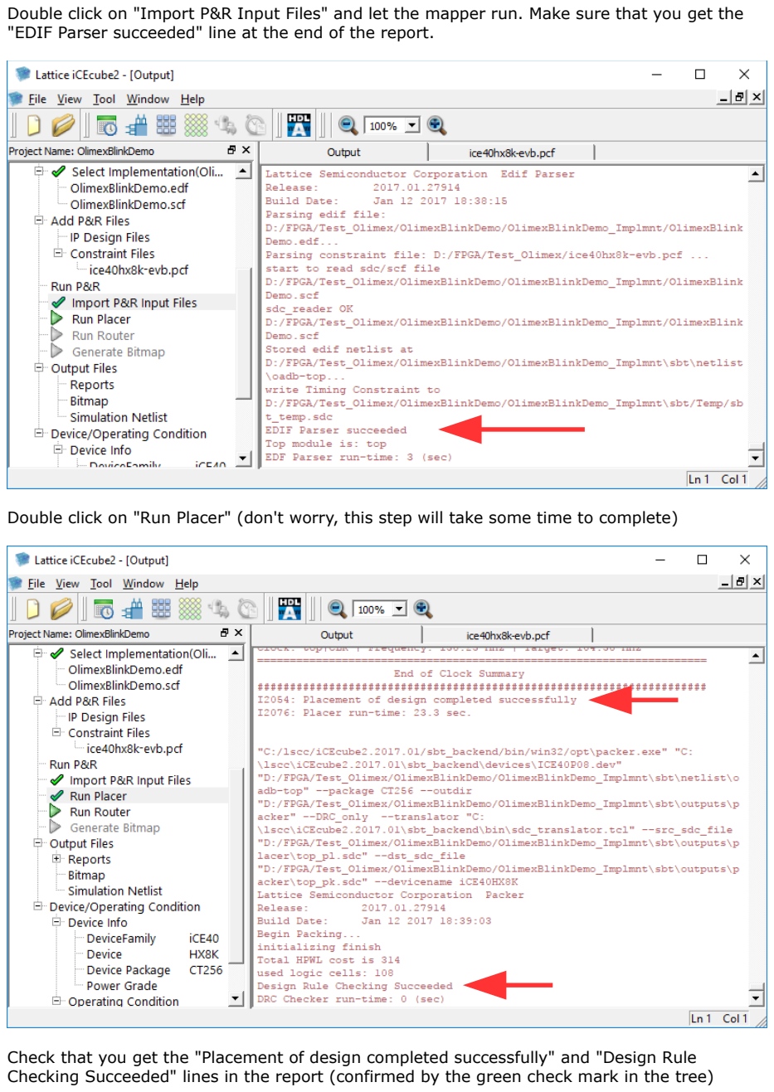
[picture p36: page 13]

Double click on "Import P&R Input Files" and let the mapper run. Make sure that you get the "EDIF Parser succeeded" line at the end of the report.

Double click on "Run Placer" (don't worry, this step will take some time to complete)

Check that you get the "Placement of design completed successfully" and "Design Rule Checking Succeeded" lines in the report (confirmed by the green check mark in the tree)

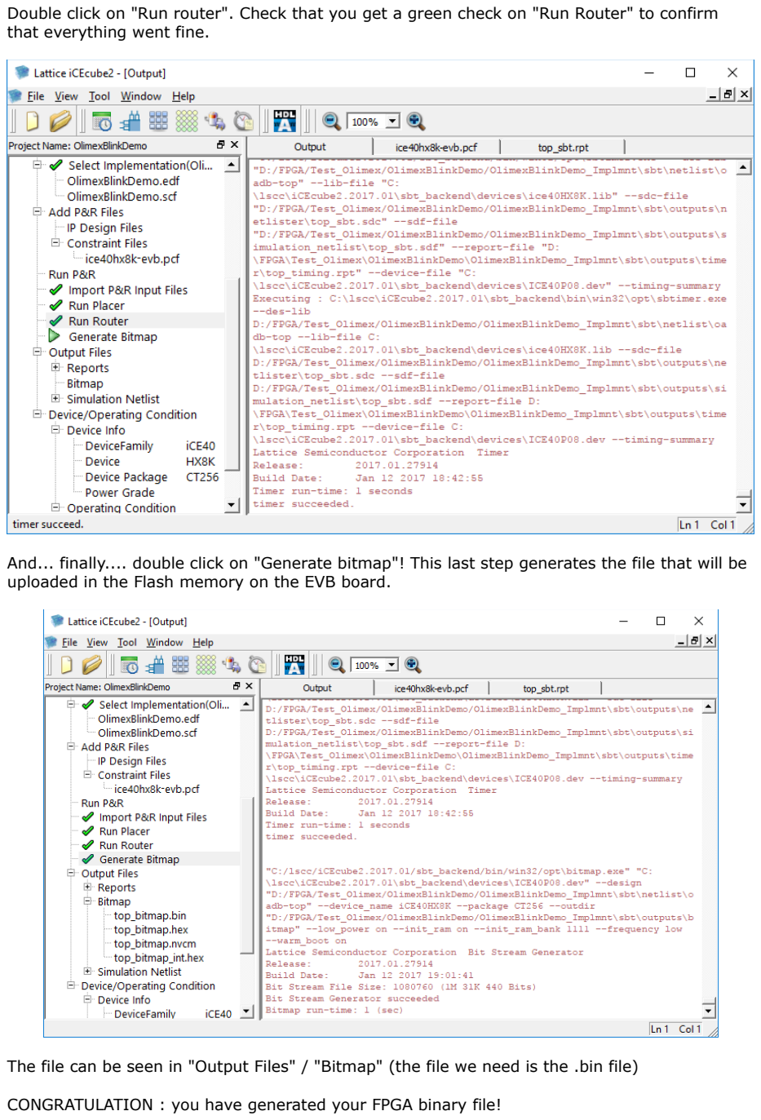
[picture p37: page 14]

Double click on "Run router". Check that you get a green check on "Run Router" to confirm that everything went fine.

And... finally.... double click on "Generate bitmap"! This last step generates the file that will be uploaded in the Flash memory on the EVB board.

The file can be seen in "Output Files" / "Bitmap" (the file we need is the .bin file)

CONGRATULATION : you have generated your FPGA binary file!

Step 3 : For the fun...

Once the bitmap file has been generated, there are two screens which are interesting to consult.

The first one is called "Floor Planner", it shows the resource used on your FPGA. When you work with big Verilog or VHDL projects, this screen is very important to know when you reach the limits of the chip you use.

Click on "Tools" / "Floor planner" menu to show the following window (it can be reached also on the button bar on the top)

Detailing the floor planner functionality is out of the scope of this starter manual. Please refer to Lattice manuals for details about this tool.

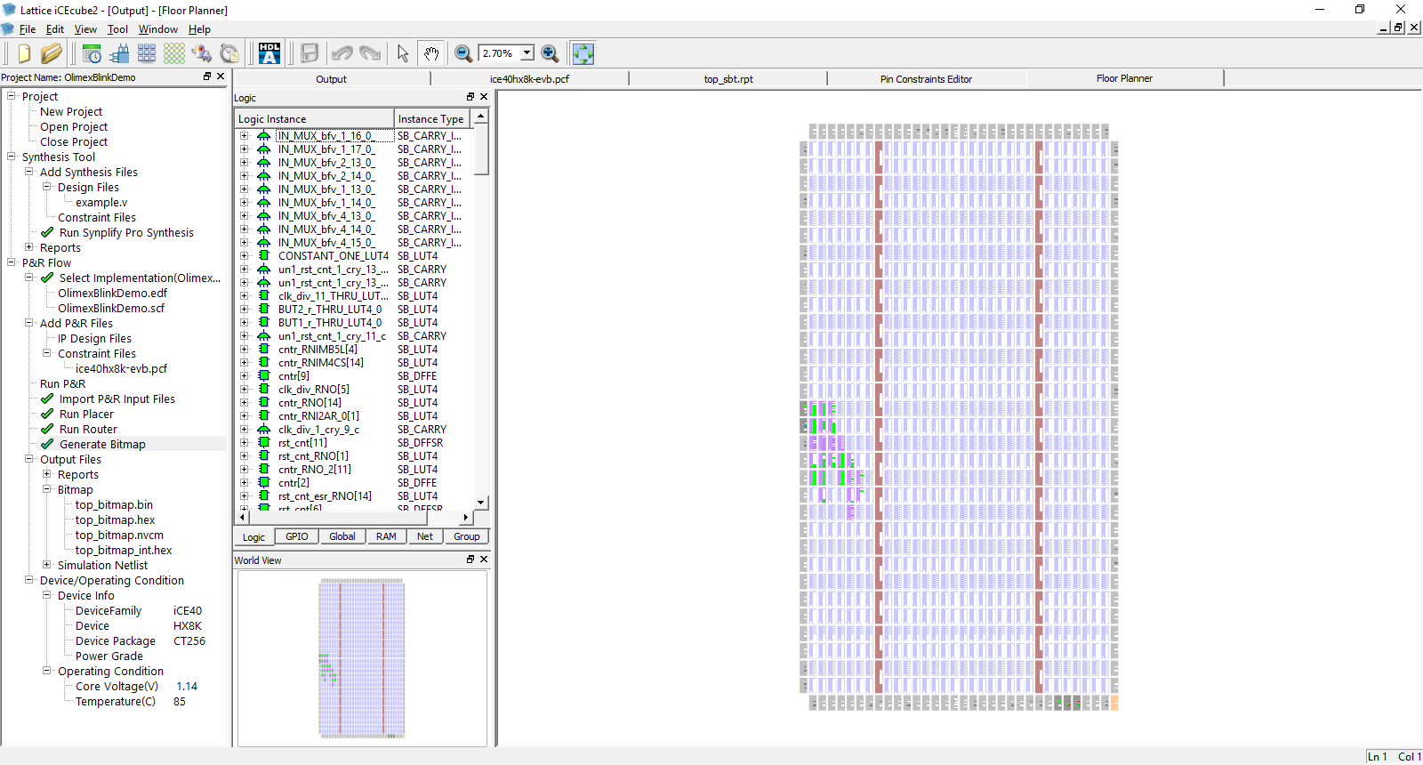
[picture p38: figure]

The second useful tool is the Package View, which shows which pin is used for which function. This window is reached by "Tool" / "Package View" menu.

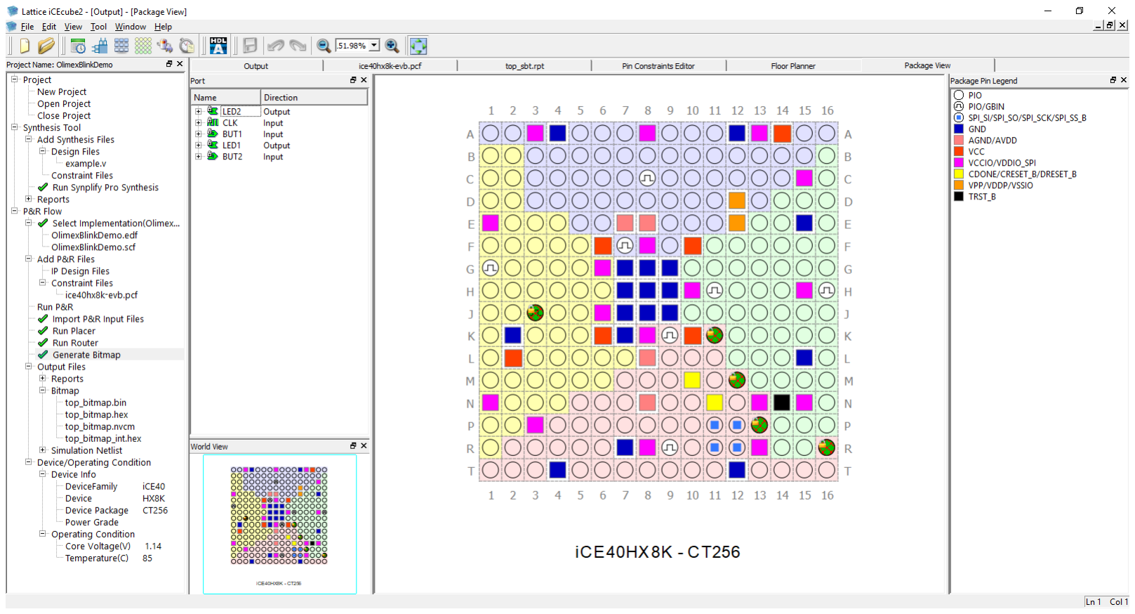
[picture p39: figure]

Step 4 : Let's go in the real world

Now that you have the FPGA binary file (the "bitmap"), you can upload it in the Olimex board.

The easiest solution is to use the Olimexino 32U4 board, loaded with the iceprogduino sketch. You will find all details about the configuration of the board on Olimex website.

You can also use another Arduino (we use here a Intel Galileo Gen2) loaded with the sketch. Note that the iceprogduino sketch is designed to run natively on Olimexino 32U4 boards only, it needs to be modified to run on Arudino Zero, Arduino Due and Intel Galileo boards. If you use a Galileo board, we can provide you the modified sketch.

TAKE AN EXTREME CARE ABOUT THE ARDUINO VOLTAGE! Do not use a +5V Arduino to program the iCE40 EVB boards, this would destroy immediately the components (the EVB runs on 3.3V only)

On Windows side, there are two programs that can be used : winiceprogduino, which has been compiled using GCC or WinProgICE, which has been compiled under Visual Studio. We prefer the second one (not only because we wrote it, but because we have enhanced the user interface). The two programs are used in the same way (they use the same basic source code).

Connection details between the Olimexino and the iCE40 boards via UEXT connector are given on Olimex website. We highly recommend to connect the iCE40 board and the programmer with power suply disconnected.

Once the programmer and the iCE40 board are connected and powered, you can start the programming software. Check the serial port number used by the Olimexino (using Windows control panel or Arduino IDE), you will need it for the programming tool.

You can easily test the connection between the two boards using the following command (depending on the software you want to use, and replace xx with Arduino serial port number)

winprogice -ICOMxx -t
or
winiceprogduino -ICOMxx -t

If you see "Winbond W25Q16" being reported, then you are sure that communication is ok between the two boards

To program a bitmap file for the FPGA, the command syntax is simple

winprogice -ICOMxx -v bitmapfile.bin
or
winiceporgduino -ICOMxx bitmapfile.bin

This command will erase automatically the Flash and will transfer the bitmap file to the Flash.

In all cases, check that you get the "Bye" message at the end. If you see the program stopping or if you see an error message, the Flash will not be programmed completely and the FPGA will not be programmed correctly and may act strangely.

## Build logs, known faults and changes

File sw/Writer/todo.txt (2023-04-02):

* add automatic smooth properties - need to work this out if needed at all
* add arrays using the braces+comma-operator and the array index operator:
   ("a", "b"", "c")[2] => "b"
   "a", "b", "c"[2] => ???

* space invaders animation
* sunset/sunrise

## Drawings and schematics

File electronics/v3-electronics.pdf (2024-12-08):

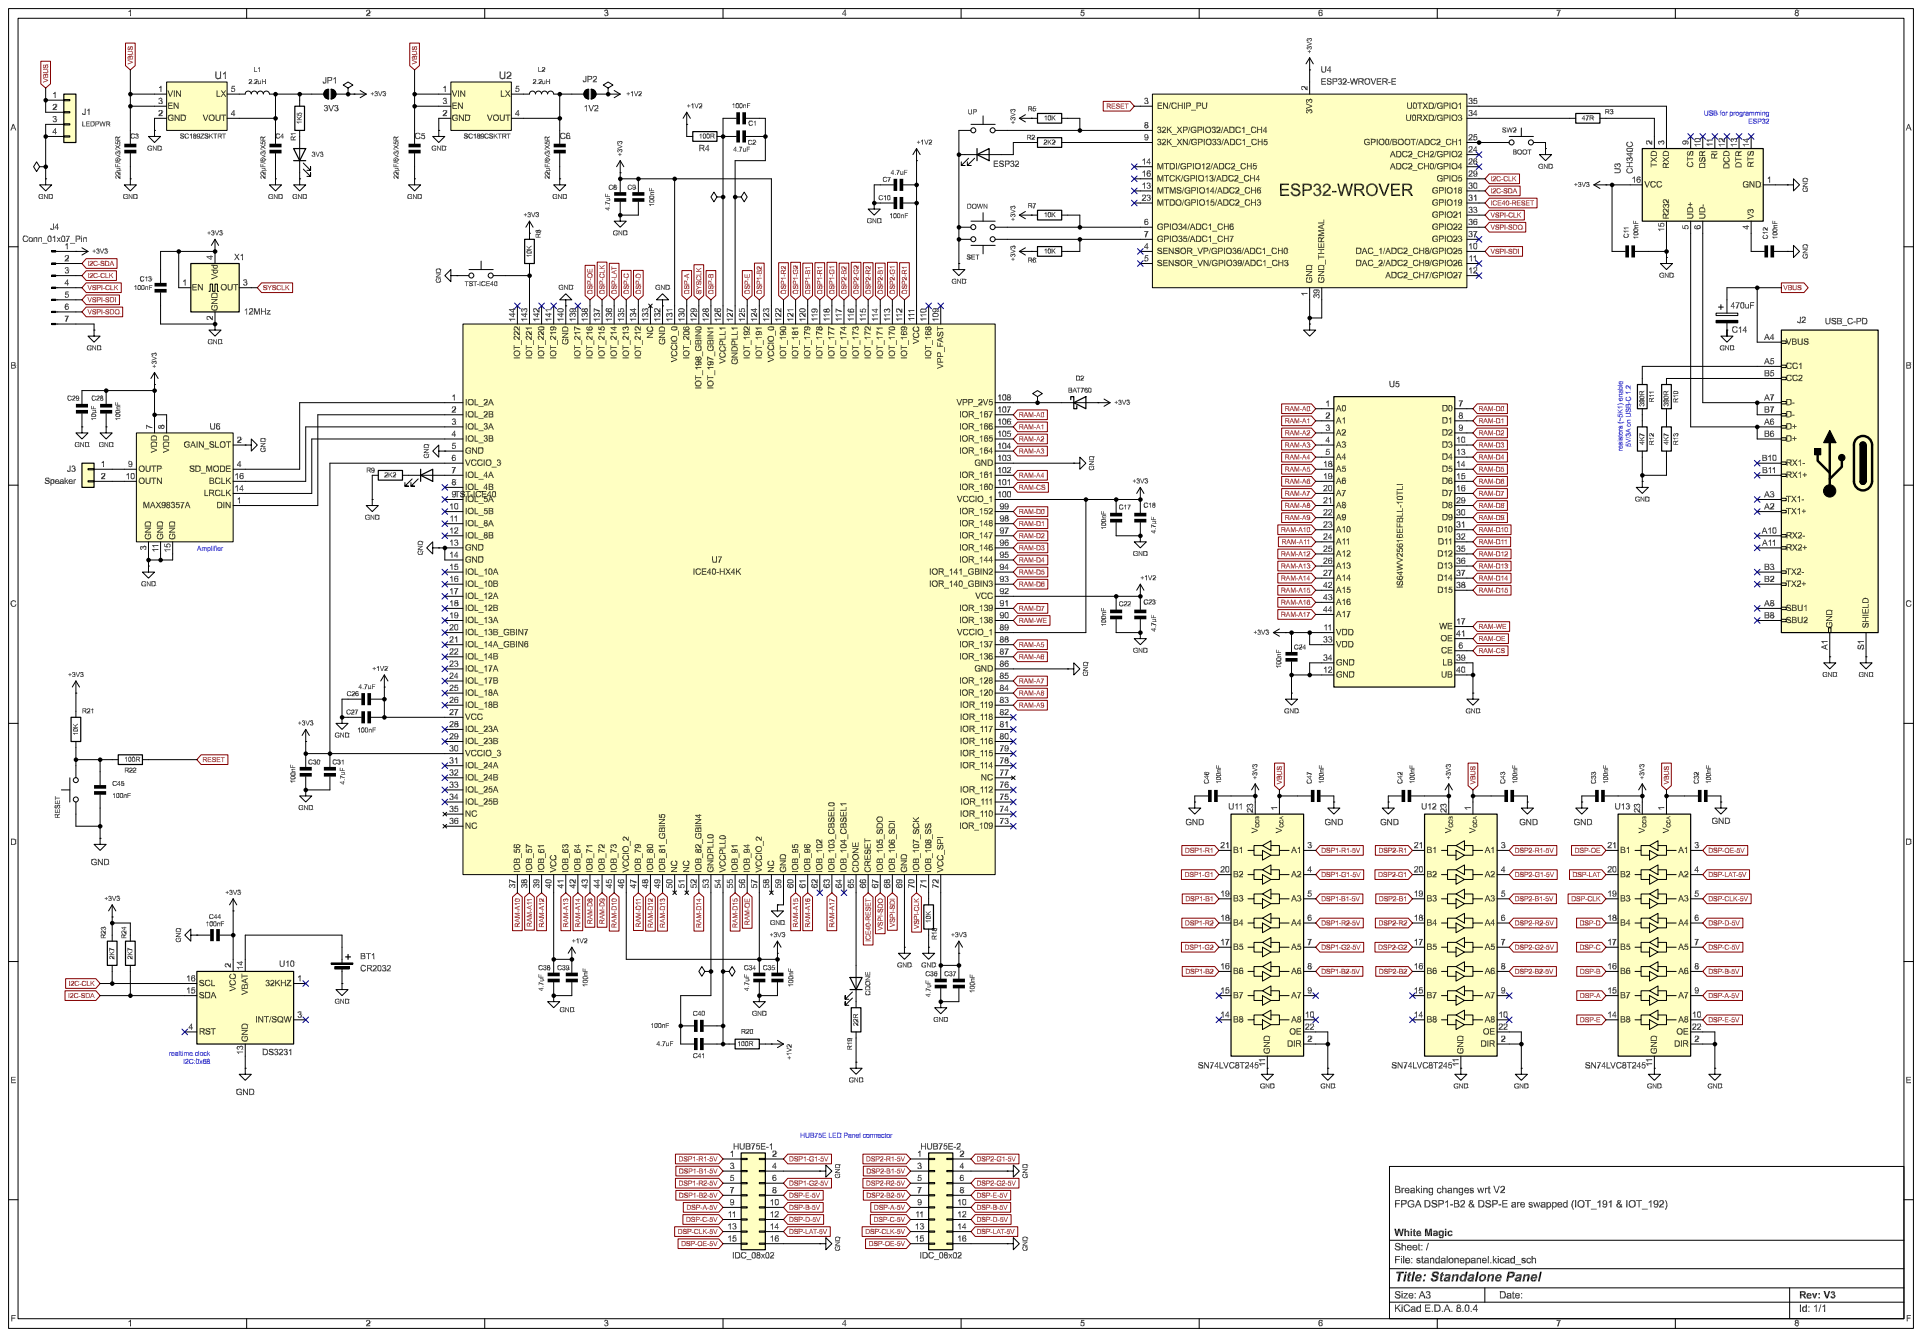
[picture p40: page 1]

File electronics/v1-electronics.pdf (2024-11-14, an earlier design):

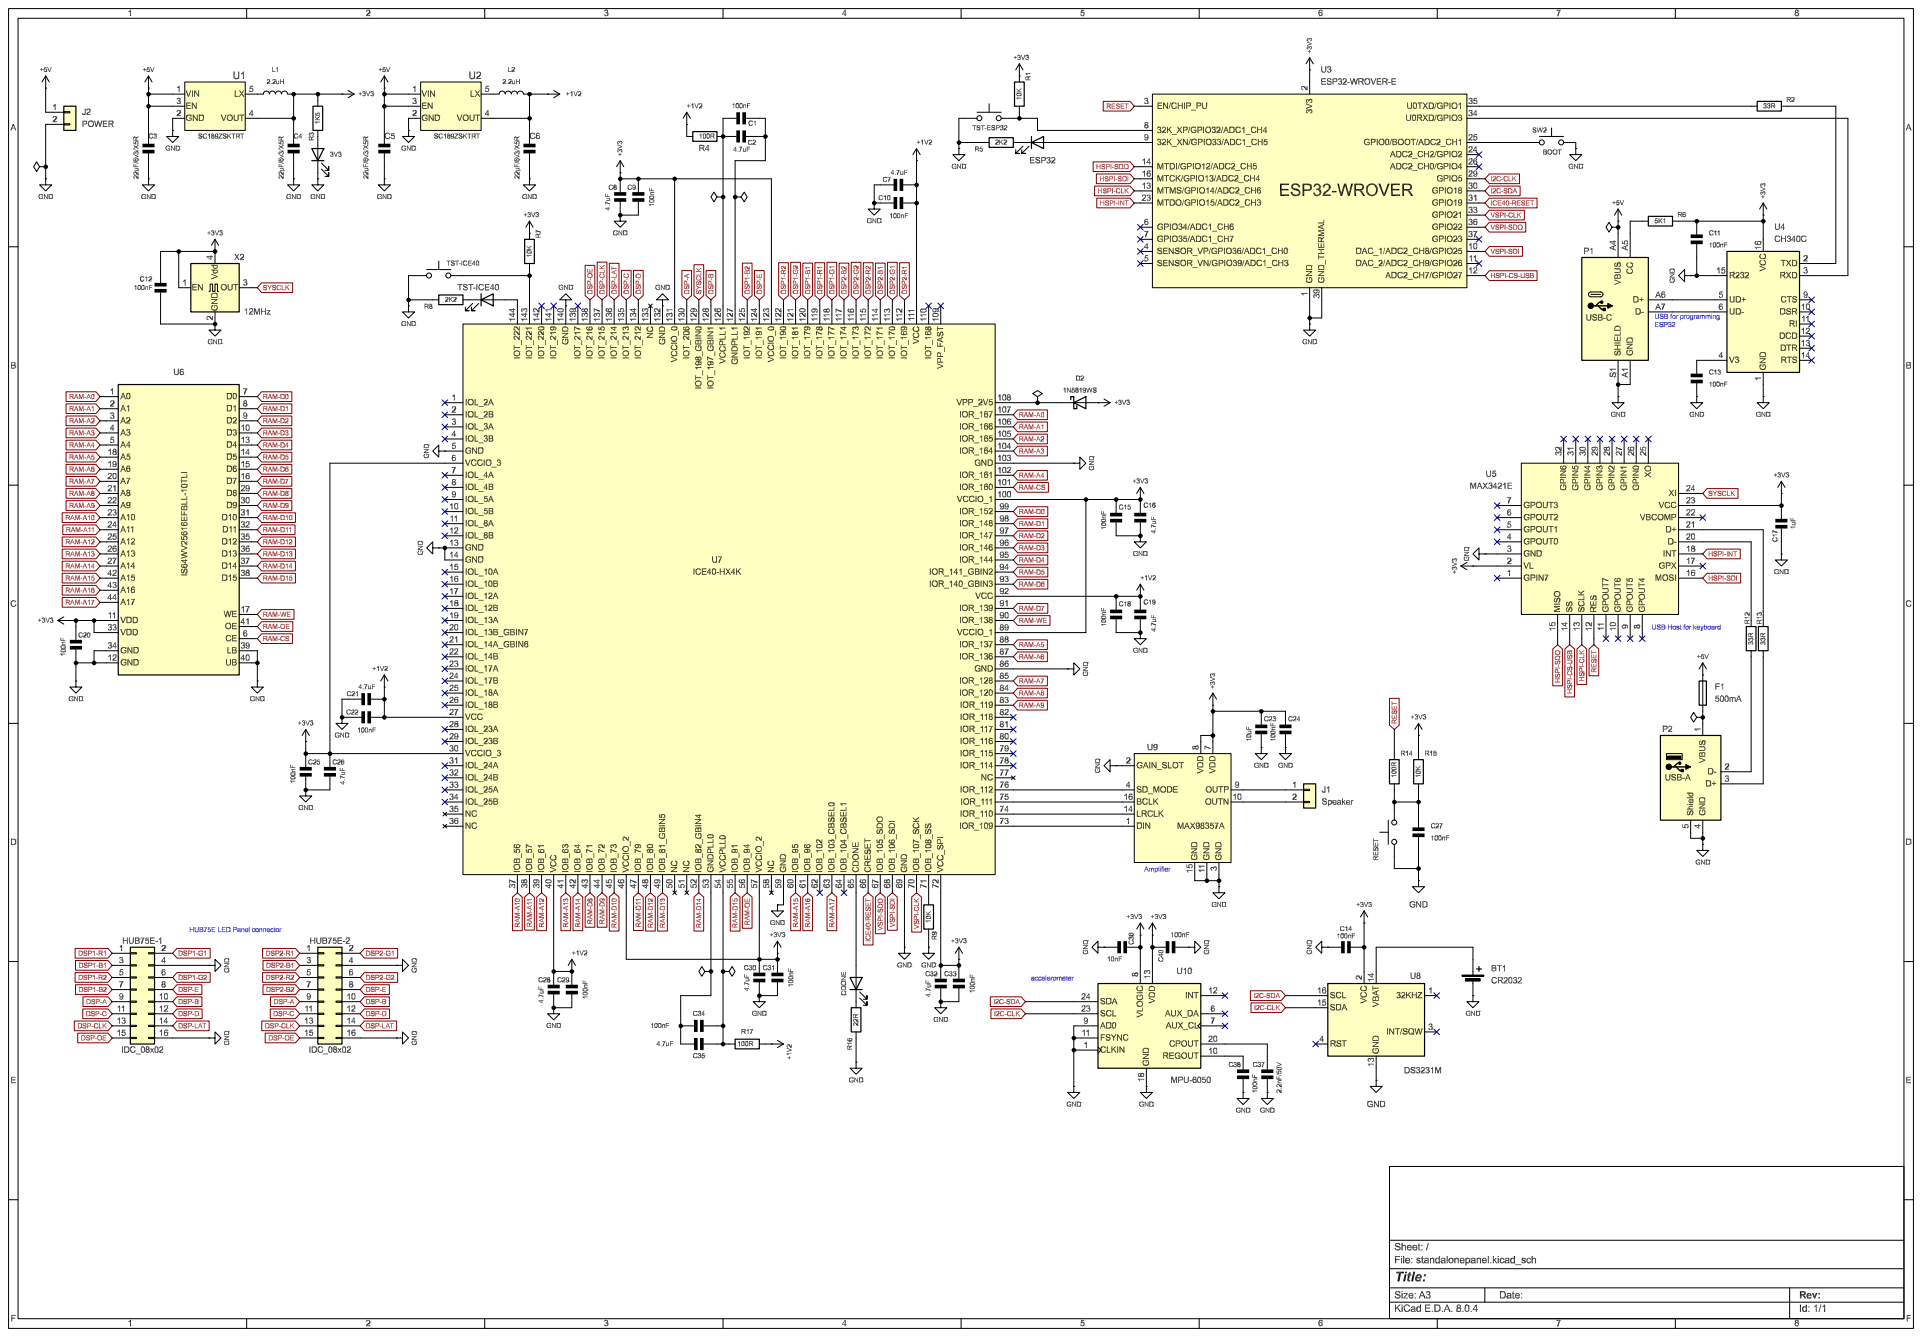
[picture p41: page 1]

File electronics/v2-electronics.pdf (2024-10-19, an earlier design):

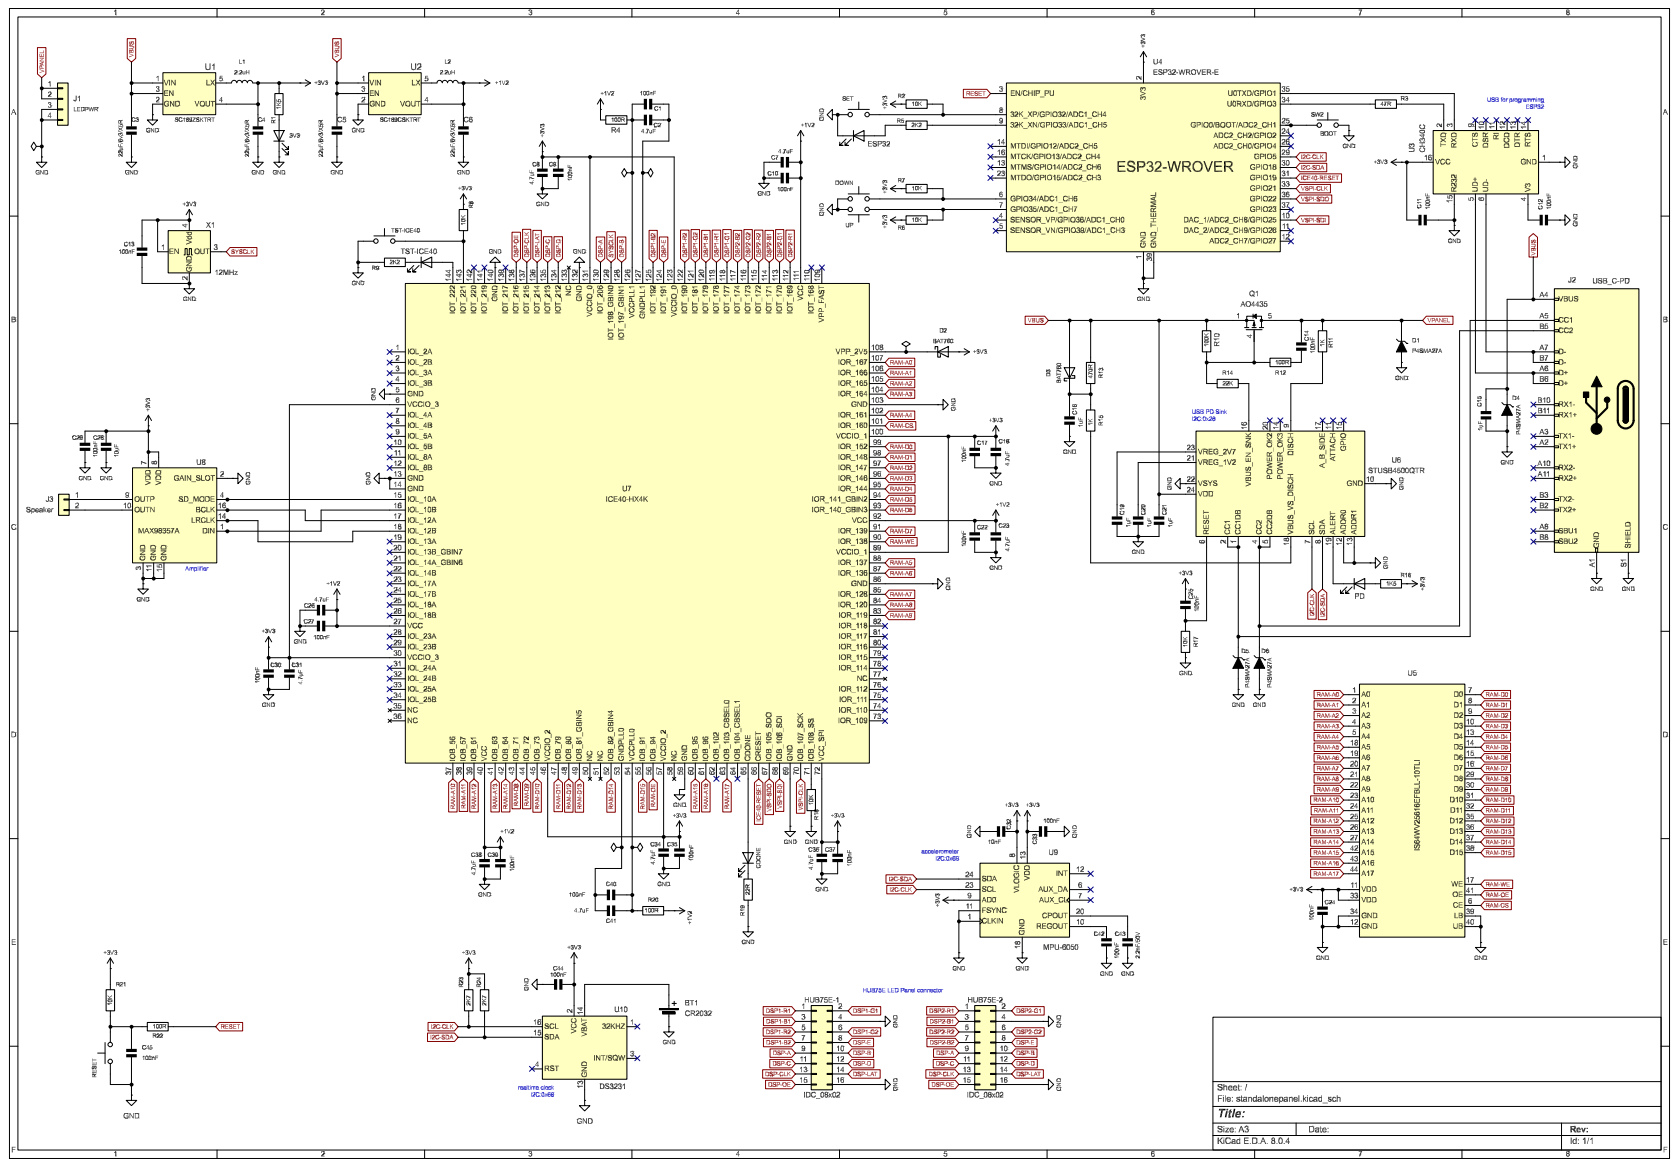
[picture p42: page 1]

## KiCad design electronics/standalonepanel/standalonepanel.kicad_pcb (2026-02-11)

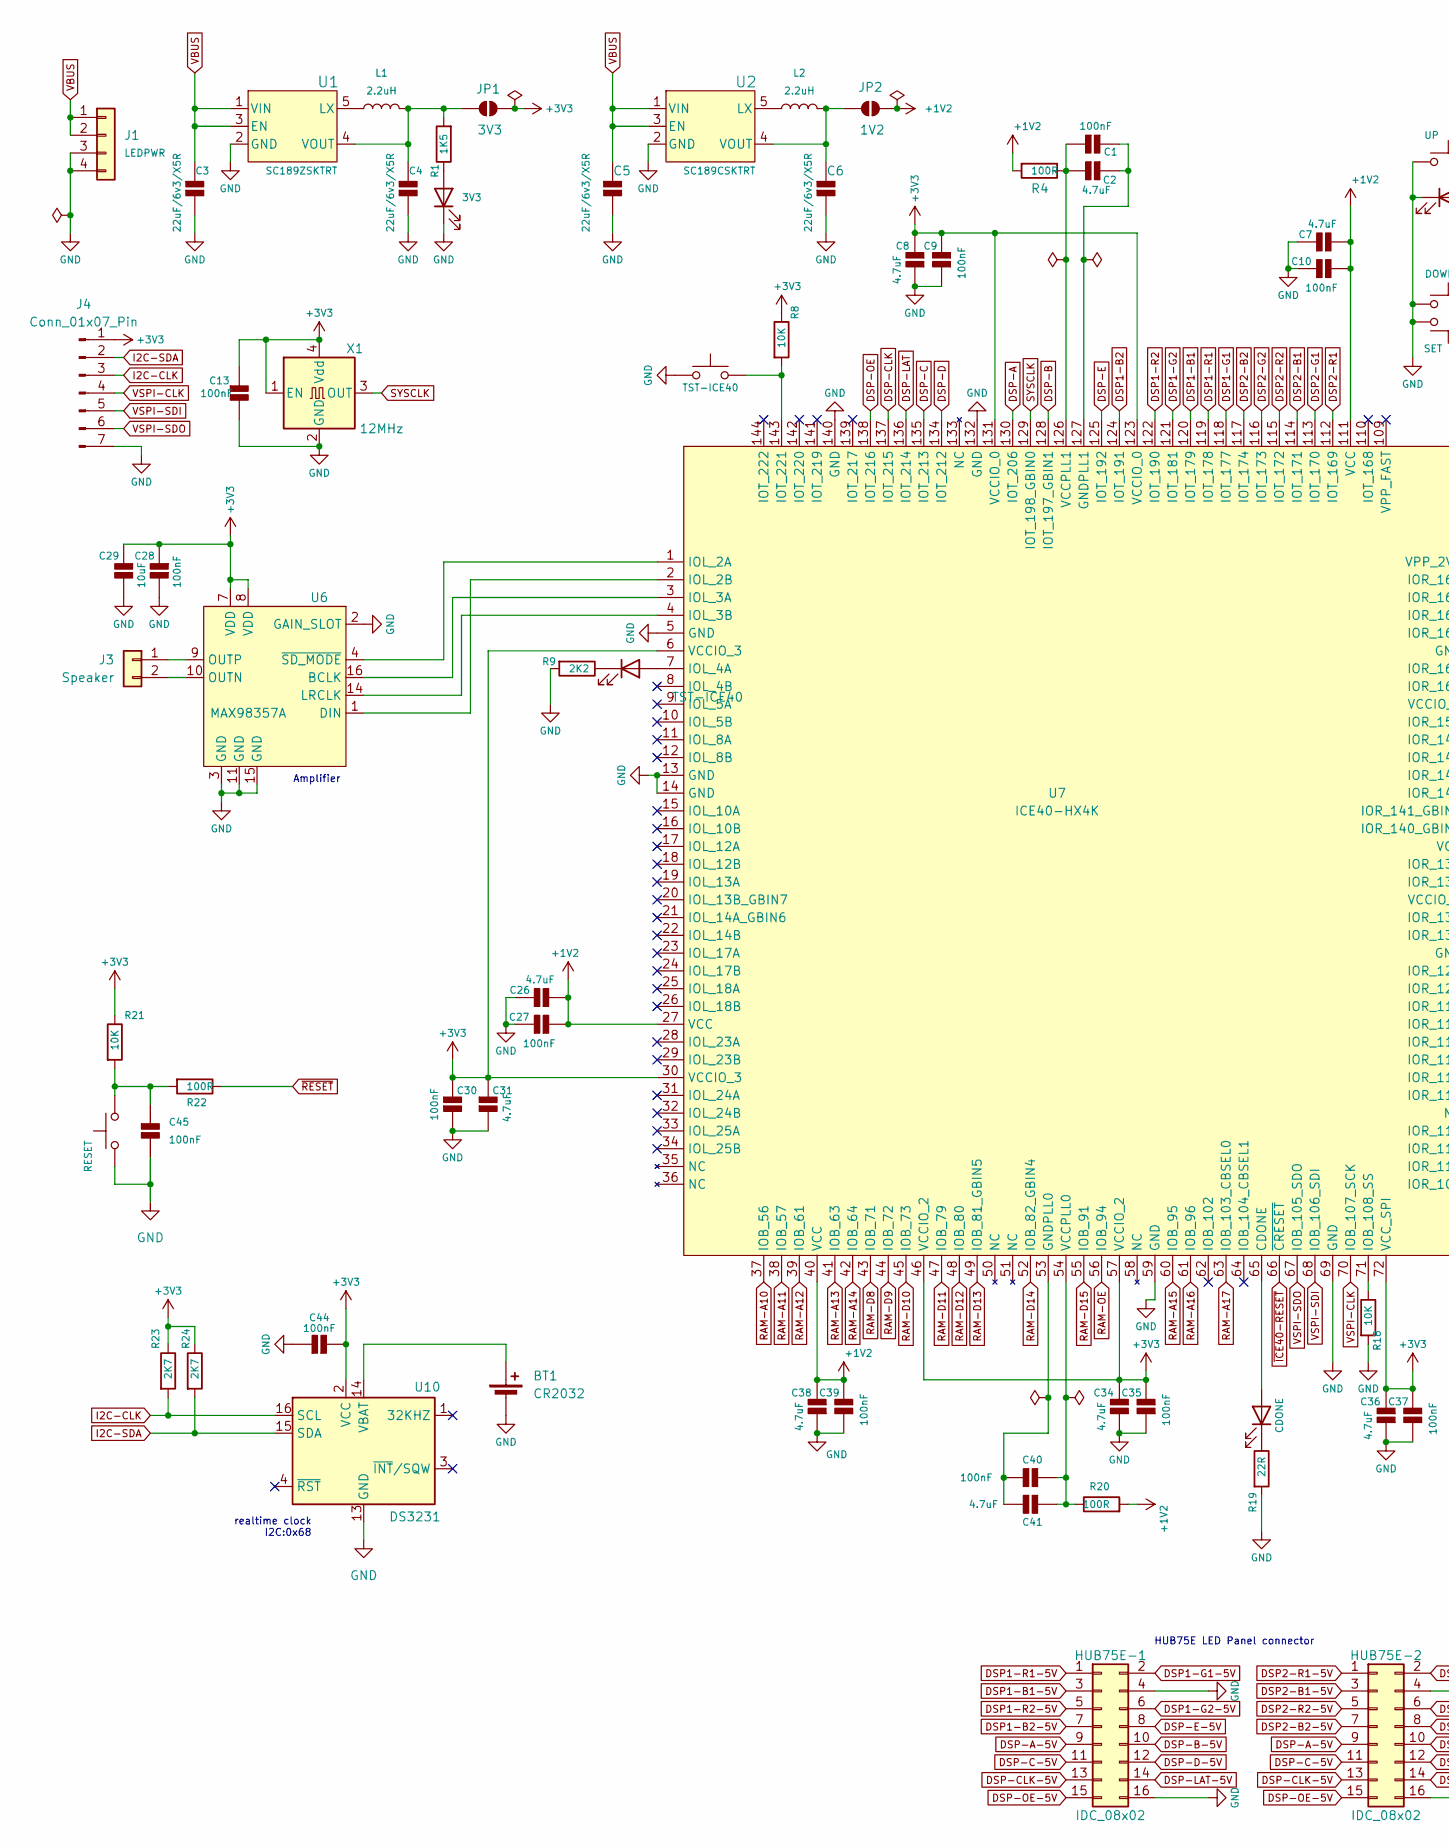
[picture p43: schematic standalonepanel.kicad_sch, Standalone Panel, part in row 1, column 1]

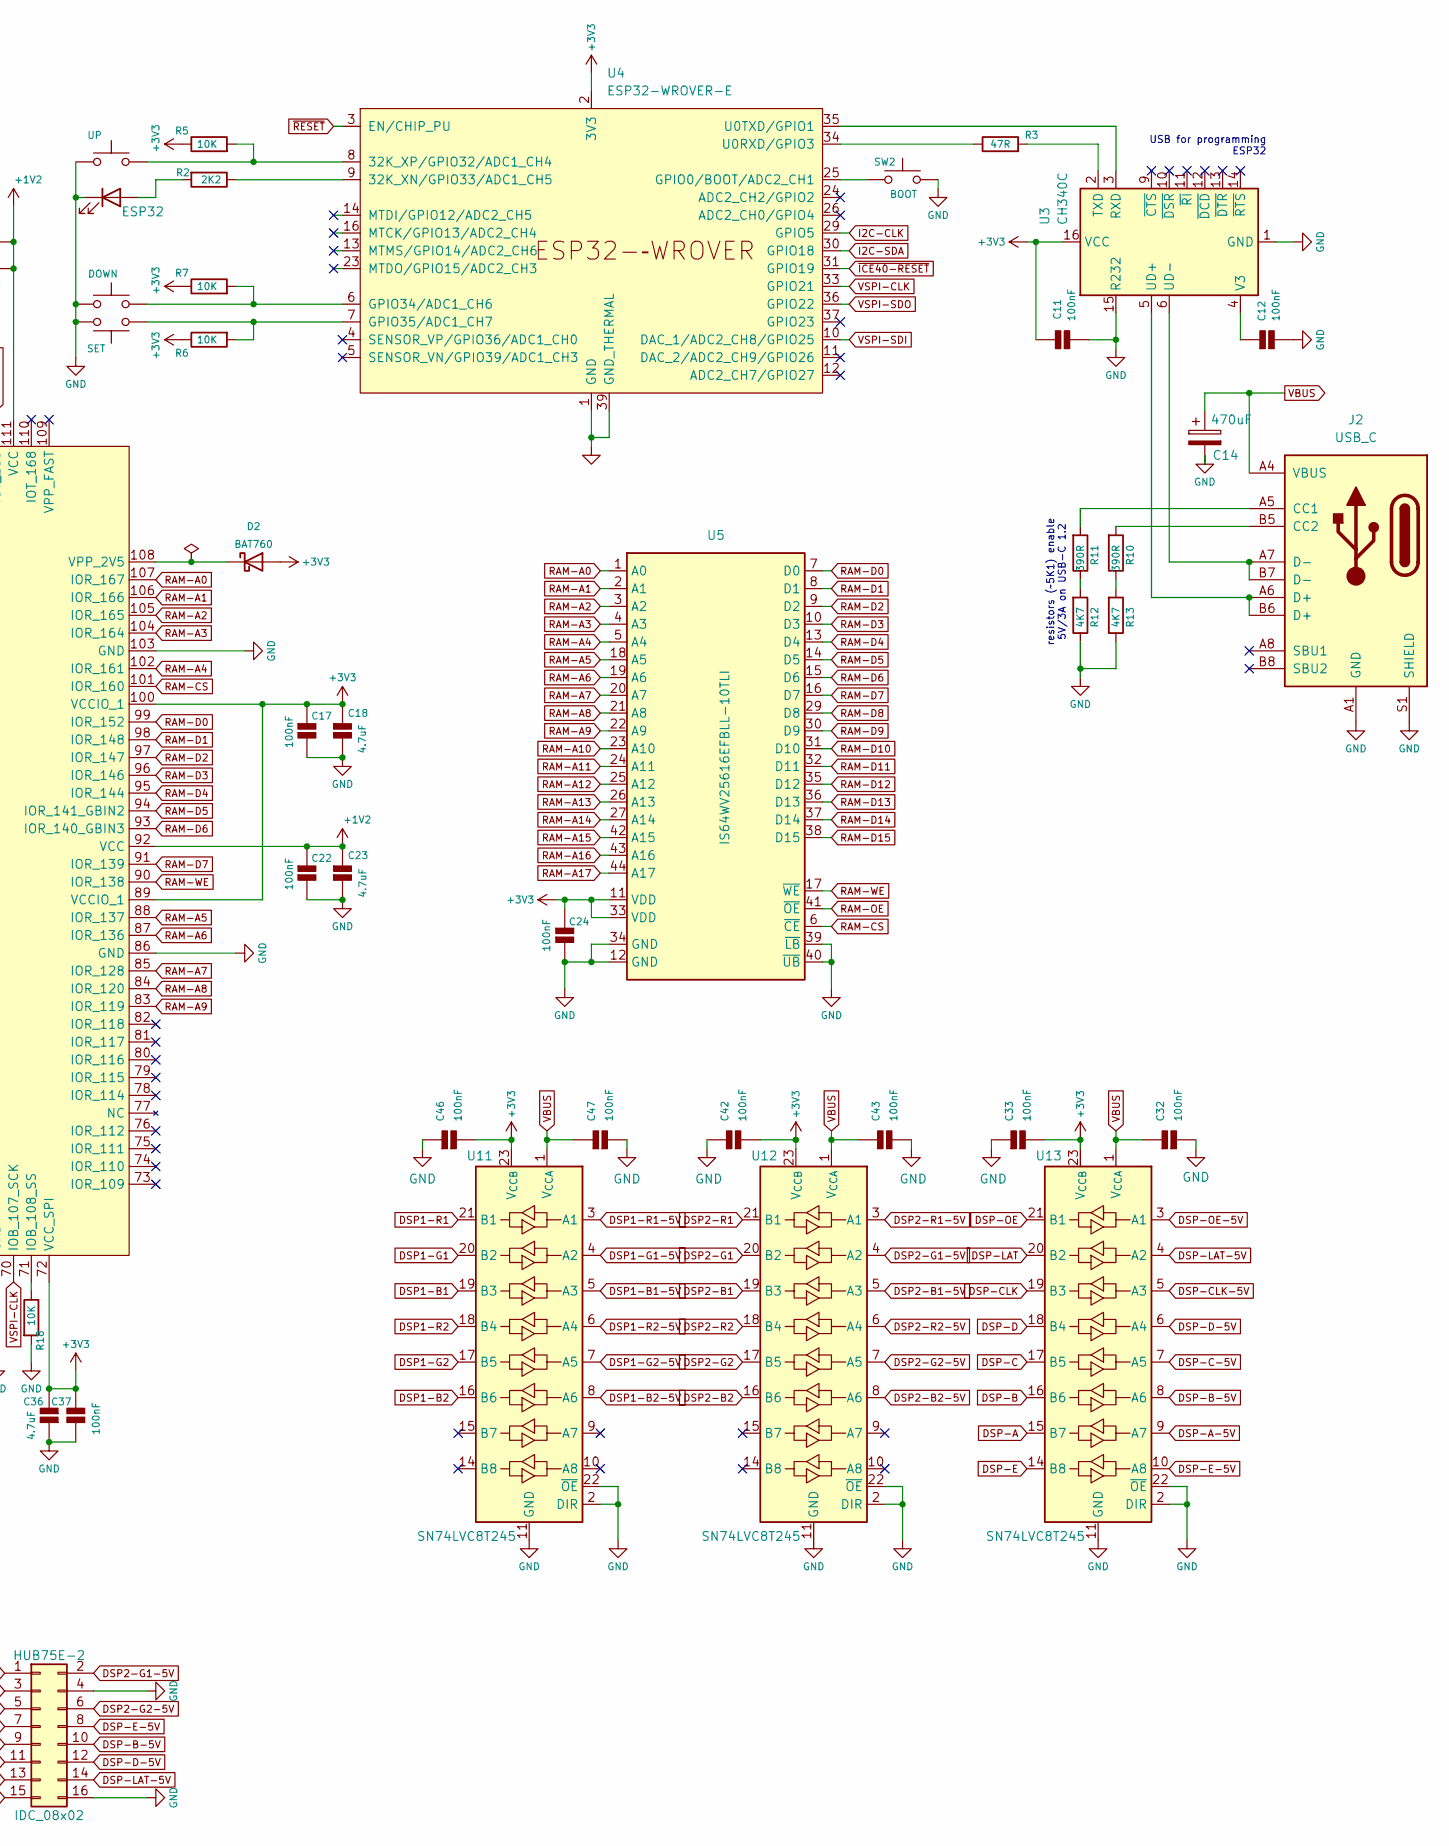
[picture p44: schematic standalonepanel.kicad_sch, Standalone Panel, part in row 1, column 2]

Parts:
BT1: CR2032; cr2032_smd_clip
C1, C9, C10, C11, C12, C13, C17, C22, C24, C27, C28, C30, C32, C33, C35, C37, C39, C40, C42, C43, C44, C45, C46, C47: 100nF; C_0805_2012Metric_Pad1.18x1.45mm_HandSolder
C2, C7, C8, C18, C23, C26, C31, C34, C36, C38, C41: 4.7uF; C_0805_2012Metric_Pad1.18x1.45mm_HandSolder
C3, C4, C5, C6: 22uF/6v3/X5R; C_0805_2012Metric_Pad1.18x1.45mm_HandSolder
C14: 470uF; C_Elec_8x10.2
C29: 10uF; C_0805_2012Metric_Pad1.18x1.45mm_HandSolder
D2: BAT760; D_SOD-323
HUB75E-1, HUB75E-2: IDC_08x02; IDC-Header_2x08_P2.54mm_Horizontal
J1: LEDPWR; JST_VH_1x04_P3.96mm_Horizontal
J2: USB_C; USB_C_Receptacle _12pins
J3: Speaker; JST_XH_S2B-XH-A_1x02_P2.50mm_Horizontal
J4: Conn_01x07_Pin; PinHeader_1x07_P2.54mm_Vertical
JP1: 3V3; SolderJumper-2_P1.3mm_Open_RoundedPad1.0x1.5mm
JP2: 1V2; SolderJumper-2_P1.3mm_Open_RoundedPad1.0x1.5mm
L1, L2: 2.2uH; Inductor-040420
LED1: 3V3; LED_1206_3216Metric_Pad1.42x1.75mm_HandSolder
LED2: ESP32; LED_1206_3216Metric_Pad1.42x1.75mm_HandSolder
LED3: TST-ICE40; LED_1206_3216Metric_Pad1.42x1.75mm_HandSolder
LED5: CDONE; LED_1206_3216Metric_Pad1.42x1.75mm_HandSolder
R1: 1K5; R_1206_3216Metric_Pad1.30x1.75mm_HandSolder
R2, R9: 2K2; R_1206_3216Metric_Pad1.30x1.75mm_HandSolder
R3: 47R; R_1206_3216Metric_Pad1.30x1.75mm_HandSolder
R4, R20, R22: 100R; R_1206_3216Metric_Pad1.30x1.75mm_HandSolder
R5, R6, R7, R8, R18, R21: 10K; R_1206_3216Metric_Pad1.30x1.75mm_HandSolder
R10, R11: 390R; R_1206_3216Metric_Pad1.30x1.75mm_HandSolder
R12, R13: 4K7; R_1206_3216Metric_Pad1.30x1.75mm_HandSolder
R19: 22R; R_1206_3216Metric_Pad1.30x1.75mm_HandSolder
R23, R24: 2K7; R_1206_3216Metric_Pad1.30x1.75mm_HandSolder
SW1: UP; SW_Tactile_SKHH_Angled
SW2: BOOT; SW_SPST_FSMSM
SW3: SET; SW_Tactile_SKHH_Angled
SW4: DOWN; SW_Tactile_SKHH_Angled
SW5: TST-ICE40; SW_SPST_FSMSM
SW6: RESET; SW_SPST_FSMSM
U1: SC189ZSKTRT; SOT23-5-SC189_SEM
U2: SC189CSKTRT; SOT23-5-SC189_SEM
U3: CH340C; SOIC-16_3.9x9.9mm_P1.27mm
U4: ESP32-WROVER-E
U5: IS64WV25616EFBLL-10TLI; TSOP-II-44_10.16x18.41mm_P0.8mm
U6: MAX98357A; TQFN-16-1EP_3x3mm_P0.5mm_EP1.6x1.6mm
U7: ICE40-HX4K; TQFP-144_20x20mm_P0.5mm
U10: DS3231; SOIC-16W_7.5x10.3mm_P1.27mm
U11, U12, U13: SN74LVC8T245; TSSOP-24_4.4x7.8mm_P0.65mm
X1: 12MHz; Oscillator_SMD_EuroQuartz_XO91-4Pin_7.0x5.0mm_HandSoldering

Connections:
+1V2: C7.2, C10.2, C22.1, C23.1, C26.2, C27.2, C38.2, C39.2, JP2.2 (B), R4.2, R20.2, U7.27 (VCC), U7.40 (VCC), U7.92 (VCC), U7.111 (VCC)
+3V3: C8.2, C9.2, C11.1, C13.1, C17.1, C18.1, C24.1, C28.1, C29.1, C30.1, C31.1, C33.2, C34.2, C35.2, C36.2, C37.2, C42.2, C44.2, C46.2, D2.2 (A), J4.1, JP1.2 (B), R5.1, R6.1, R7.1, R8.1, R21.1, R23.1, R24.1, U3.16 (VCC), U4.2 (3V3), U5.11 (VDD), U5.33 (VDD), U6.7 (VDD), U6.8 (VDD), U7.6 (VCCIO_3), U7.30 (VCCIO_3), U7.46 (VCCIO_2), U7.57 (VCCIO_2), U7.72 (VCC_SPI), U7.89 (VCCIO_1), U7.100 (VCCIO_1), U7.123 (VCCIO_0), U7.131 (VCCIO_0), U10.2 (VCC), U11.23 (V_{CCB}), U11.24 (V_{CCB}), U12.23 (V_{CCB}), U12.24 (V_{CCB}), U13.23 (V_{CCB}), U13.24 (V_{CCB}), X1.1 (EN), X1.4 (Vdd)
DSP1-B1: U7.120 (IOT_179), U11.19 (B3)
DSP1-B1-5V: HUB75E-1.3, U11.5 (A3)
DSP1-B2: U7.124 (IOT_191), U11.16 (B6)
DSP1-B2-5V: HUB75E-1.7, U11.8 (A6)
DSP1-G1: U7.118 (IOT_177), U11.20 (B2)
DSP1-G1-5V: HUB75E-1.2, U11.4 (A2)
DSP1-G2: U7.121 (IOT_181), U11.17 (B5)
DSP1-G2-5V: HUB75E-1.6, U11.7 (A5)
DSP1-R1: U7.119 (IOT_178), U11.21 (B1)
DSP1-R1-5V: HUB75E-1.1, U11.3 (A1)
DSP1-R2: U7.122 (IOT_190), U11.18 (B4)
DSP1-R2-5V: HUB75E-1.5, U11.6 (A4)
DSP2-B1: U7.114 (IOT_171), U12.19 (B3)
DSP2-B1-5V: HUB75E-2.3, U12.5 (A3)
DSP2-B2: U7.117 (IOT_174), U12.16 (B6)
DSP2-B2-5V: HUB75E-2.7, U12.8 (A6)
DSP2-G1: U7.113 (IOT_170), U12.20 (B2)
DSP2-G1-5V: HUB75E-2.2, U12.4 (A2)
DSP2-G2: U7.116 (IOT_173), U12.17 (B5)
DSP2-G2-5V: HUB75E-2.6, U12.7 (A5)
DSP2-R1: U7.112 (IOT_169), U12.21 (B1)
DSP2-R1-5V: HUB75E-2.1, U12.3 (A1)
DSP2-R2: U7.115 (IOT_172), U12.18 (B4)
DSP2-R2-5V: HUB75E-2.5, U12.6 (A4)
DSP-A: U7.130 (IOT_206), U13.15 (B7)
DSP-A-5V: HUB75E-1.9, HUB75E-2.9, U13.9 (A7)
DSP-B: U7.128 (IOT_197_GBIN1), U13.16 (B6)
DSP-B-5V: HUB75E-1.10, HUB75E-2.10, U13.8 (A6)
DSP-C: U7.135 (IOT_213), U13.17 (B5)
DSP-C-5V: HUB75E-1.11, HUB75E-2.11, U13.7 (A5)
DSP-CLK: U7.137 (IOT_215), U13.19 (B3)
DSP-CLK-5V: HUB75E-1.13, HUB75E-2.13, U13.5 (A3)
DSP-D: U7.134 (IOT_212), U13.18 (B4)
DSP-D-5V: HUB75E-1.12, HUB75E-2.12, U13.6 (A4)
DSP-E: U7.125 (IOT_192), U13.14 (B8)
DSP-E-5V: HUB75E-1.8, HUB75E-2.8, U13.10 (A8)
DSP-LAT: U7.136 (IOT_214), U13.20 (B2)
DSP-LAT-5V: HUB75E-1.14, HUB75E-2.14, U13.4 (A2)
DSP-OE: U7.138 (IOT_216), U13.21 (B1)
DSP-OE-5V: HUB75E-1.15, HUB75E-2.15, U13.3 (A1)
GND: BT1.2 (-), C3.2, C4.2, C5.2, C6.2, C7.1, C8.1, C9.1, C10.1, C11.2, C12.2, C13.2, C14.2, C17.2, C18.2, C22.2, C23.2, C24.2, C26.1, C27.1, C28.2, C29.2, C30.2, C31.2, C32.2, C33.1, C34.1, C35.1, C36.1, C37.1, C38.1, C39.1, C42.1, C43.2, C44.1, C45.2, C46.1, C47.2, HUB75E-1.4, HUB75E-1.16, HUB75E-2.4, HUB75E-2.16, J1.3, J1.4, J2.A1 (GND), J2.A12 (GND), J2.B1 (GND), J2.B12 (GND), J2.S1 (SHIELD), J4.7, LED1.1 (K), LED2.1 (K), R9.2, R12.1, R13.1, R18.2, R19.2, SW1.1, SW2.2, SW3.1, SW4.1, SW5.1, SW6.1, U1.2 (GND), U2.2 (GND), U3.1 (GND), U3.15 (R232), U4.1 (GND), U4.15 (GND), U4.38 (GND), U4.39 (GND_THERMAL), U5.12 (GND), U5.34 (GND), U5.39 (~LB), U5.40 (~UB), U6.2 (GAIN_SLOT), U6.3 (GND), U6.11 (GND), U6.15 (GND), U7.5 (GND), U7.13 (GND), U7.14 (GND), U7.59 (GND), U7.69 (GND), U7.86 (GND), U7.103 (GND), U7.132 (GND), U7.140 (GND), U10.5 (GND), U10.6 (GND), U10.7 (GND), U10.8 (GND), U10.9 (GND), U10.10 (GND), U10.11 (GND), U10.12 (GND), U10.13 (GND), U11.2 (DIR), U11.11 (GND), U11.12 (GND), U11.13 (GND), U11.22 (~OE), U12.2 (DIR), U12.11 (GND), U12.12 (GND), U12.13 (GND), U12.22 (~OE), U13.2 (DIR), U13.11 (GND), U13.12 (GND), U13.13 (GND), U13.22 (~OE), X1.2 (GND)
I2C-CLK: J4.3, R23.2, U4.29 (GPIO5), U10.16 (SCL)
I2C-SDA: J4.2, R24.2, U4.30 (GPIO18), U10.15 (SDA)
unnamed: BT1.1 (+), U10.14 (VBAT)
unnamed: C45.1, R21.2, R22.2, SW6.2
unnamed: D2.1 (K), U7.108 (VPP_2V5)
unnamed: J2.A5 (CC1), R11.2
unnamed: J2.B5 (CC2), R10.2
unnamed: J3.1, U6.9 (OUTP)
unnamed: J3.2, U6.10 (OUTN)
unnamed: C4.1, JP1.1 (A), L1.2, R1.2, U1.4 (VOUT)
unnamed: C6.1, JP2.1 (A), L2.2, U2.4 (VOUT)
unnamed: LED1.2 (A), R1.1
unnamed: LED2.2 (A), R2.2
unnamed: LED3.2 (A), U7.7 (IOL_4A)
unnamed: LED3.1 (K), R9.1
unnamed: LED5.2 (A), U7.65 (CDONE)
unnamed: LED5.1 (K), R19.1
unnamed: R10.1, R13.2
unnamed: R11.1, R12.2
unnamed: L1.1, U1.5 (LX)
unnamed: L2.1, U2.5 (LX)
unnamed: U3.3 (RXD), U4.35 (U0TXD/GPIO1)
unnamed: R3.2, U3.2 (TXD)
unnamed: J2.A6 (D+), J2.B6 (D+), U3.5 (UD+)
unnamed: J2.A7 (D-), J2.B7 (D-), U3.6 (UD-)
unnamed: C12.1, U3.4 (V3)
unnamed: R2.1, U4.9 (32K_XN/GPIO33/ADC1_CH5)
unnamed: R5.2, SW1.2, U4.8 (32K_XP/GPIO32/ADC1_CH4)
unnamed: SW2.1, U4.25 (GPIO0/BOOT/ADC2_CH1)
unnamed: R7.2, SW4.2, U4.6 (GPIO34/ADC1_CH6)
unnamed: R6.2, SW3.2, U4.7 (GPIO35/ADC1_CH7)
unnamed: R3.1, U4.34 (U0RXD/GPIO3)
unnamed: U6.16 (BCLK), U7.3 (IOL_3A)
unnamed: U6.1 (DIN), U7.2 (IOL_2B)
unnamed: U6.14 (LRCLK), U7.4 (IOL_3B)
unnamed: U6.4 (~SD_MODE), U7.1 (IOL_2A)
unnamed: C40.2, C41.2, U7.53 (GNDPLL0)
unnamed: C1.1, C2.1, U7.127 (GNDPLL1)
unnamed: R18.1, U7.71 (IOB_108_SS)
unnamed: R8.2, SW5.2, U7.143 (IOT_221)
unnamed: C40.1, C41.1, R20.1, U7.54 (VCCPLL0)
unnamed: C1.2, C2.2, R4.1, U7.126 (VCCPLL1)
RAM-A0: U5.1 (A0), U7.107 (IOR_167)
RAM-A1: U5.2 (A1), U7.106 (IOR_166)
RAM-A2: U5.3 (A2), U7.105 (IOR_165)
RAM-A3: U5.4 (A3), U7.104 (IOR_164)
RAM-A4: U5.5 (A4), U7.102 (IOR_161)
RAM-A5: U5.18 (A5), U7.88 (IOR_137)
RAM-A6: U5.19 (A6), U7.87 (IOR_136)
RAM-A7: U5.20 (A7), U7.85 (IOR_128)
RAM-A8: U5.21 (A8), U7.84 (IOR_120)
RAM-A9: U5.22 (A9), U7.83 (IOR_119)
RAM-A10: U5.23 (A10), U7.37 (IOB_56)
RAM-A11: U5.24 (A11), U7.38 (IOB_57)
RAM-A12: U5.25 (A12), U7.39 (IOB_61)
RAM-A13: U5.26 (A13), U7.41 (IOB_63)
RAM-A14: U5.27 (A14), U7.42 (IOB_64)
RAM-A15: U5.42 (A15), U7.60 (IOB_95)
RAM-A16: U5.43 (A16), U7.61 (IOB_96)
RAM-A17: U5.44 (A17), U7.63 (IOB_103_CBSEL0)
RAM-CS: U5.6 (~CE), U7.101 (IOR_160)
RAM-D0: U5.7 (D0), U7.99 (IOR_152)
RAM-D1: U5.8 (D1), U7.98 (IOR_148)
RAM-D2: U5.9 (D2), U7.97 (IOR_147)
RAM-D3: U5.10 (D3), U7.96 (IOR_146)
RAM-D4: U5.13 (D4), U7.95 (IOR_144)
RAM-D5: U5.14 (D5), U7.94 (IOR_141_GBIN2)
RAM-D6: U5.15 (D6), U7.93 (IOR_140_GBIN3)
RAM-D7: U5.16 (D7), U7.91 (IOR_139)
RAM-D8: U5.29 (D8), U7.43 (IOB_71)
RAM-D9: U5.30 (D9), U7.44 (IOB_72)
RAM-D10: U5.31 (D10), U7.45 (IOB_73)
RAM-D11: U5.32 (D11), U7.47 (IOB_79)
RAM-D12: U5.35 (D12), U7.48 (IOB_80)
RAM-D13: U5.36 (D13), U7.49 (IOB_81_GBIN5)
RAM-D14: U5.37 (D14), U7.52 (IOB_82_GBIN4)
RAM-D15: U5.38 (D15), U7.55 (IOB_91)
RAM-OE: U5.41 (~OE), U7.56 (IOB_94)
RAM-WE: U5.17 (~WE), U7.90 (IOR_138)
SYSCLK: U7.129 (IOT_198_GBIN0), X1.3 (OUT)
VBUS: C3.1, C5.1, C14.1, C32.1, C43.1, C47.1, J1.1, J1.2, J2.A4 (VBUS), J2.A9 (VBUS), J2.B4 (VBUS), J2.B9 (VBUS), U1.1 (VIN), U1.3 (EN), U2.1 (VIN), U2.3 (EN), U11.1 (V_{CCA}), U12.1 (V_{CCA}), U13.1 (V_{CCA})
VSPI-CLK: J4.4, U4.33 (GPIO21), U7.70 (IOB_107_SCK)
VSPI-SDI: J4.5, U4.10 (DAC_1/ADC2_CH8/GPIO25), U7.68 (IOB_106_SDI)
VSPI-SDO: J4.6, U4.36 (GPIO22), U7.67 (IOB_105_SDO)
~ICE40-RESET: U4.31 (GPIO19), U7.66 (~CRESET)
~RESET: R22.1, U4.3 (EN/CHIP_PU)

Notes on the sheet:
Amplifier
resistors (~5K1) enable 5V/3A on USB-C 1.2
USB for programming ESP32
HUB75E LED Panel connector
realtime clock I2C:0x68

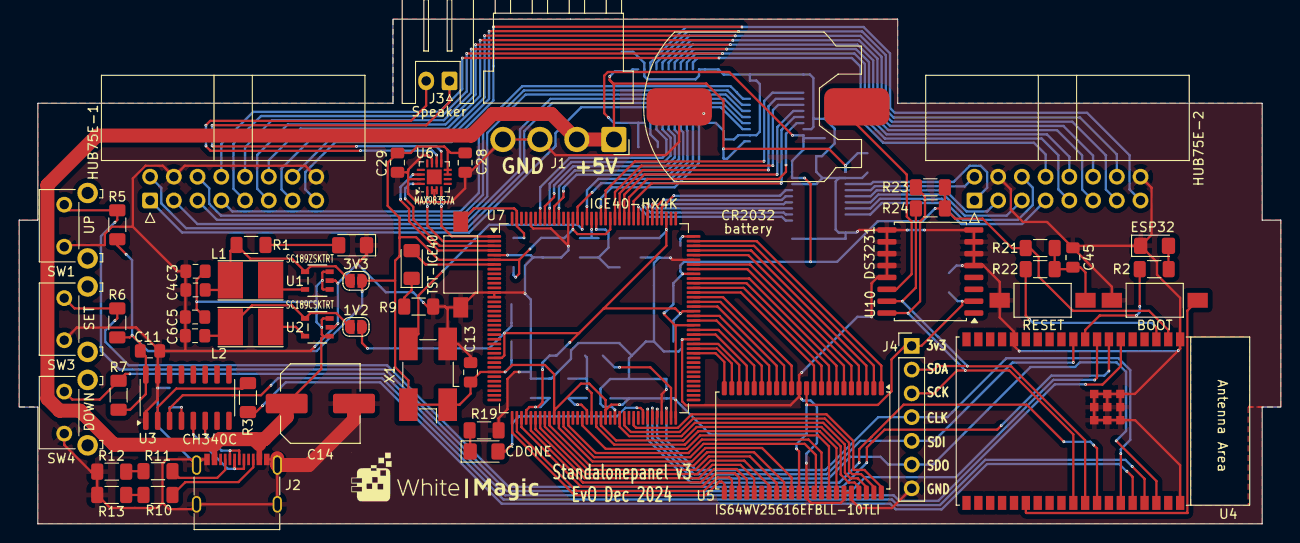
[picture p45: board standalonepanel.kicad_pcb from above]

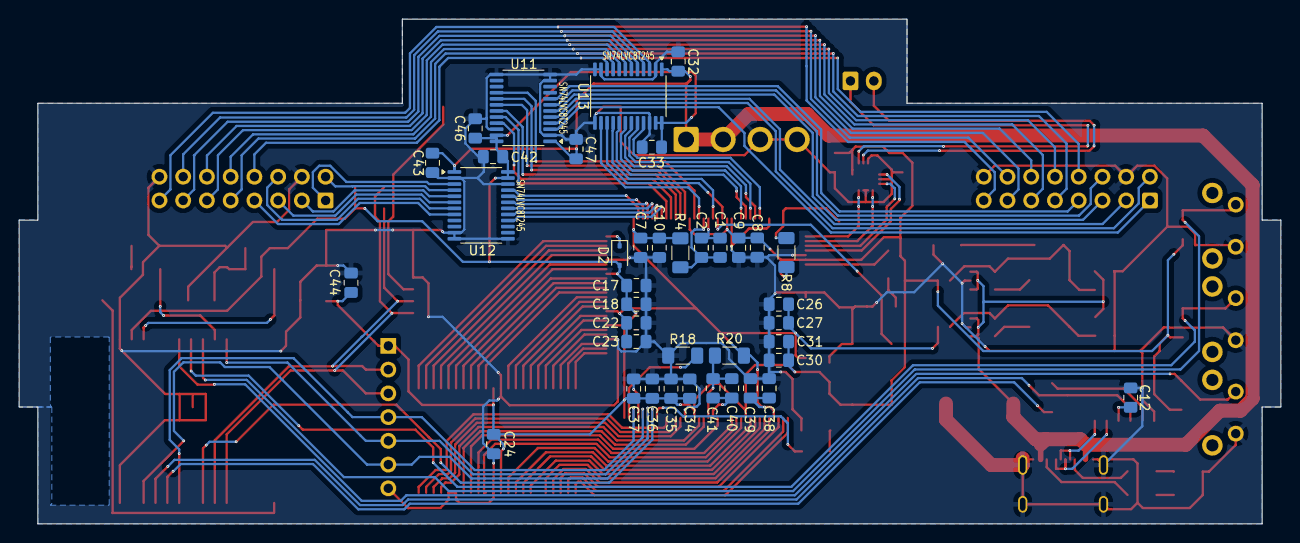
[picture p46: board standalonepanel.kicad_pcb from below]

Board: 2 copper layers, 135.0 x 54.0 mm, 95 parts (39 on the bottom side), 129 nets.

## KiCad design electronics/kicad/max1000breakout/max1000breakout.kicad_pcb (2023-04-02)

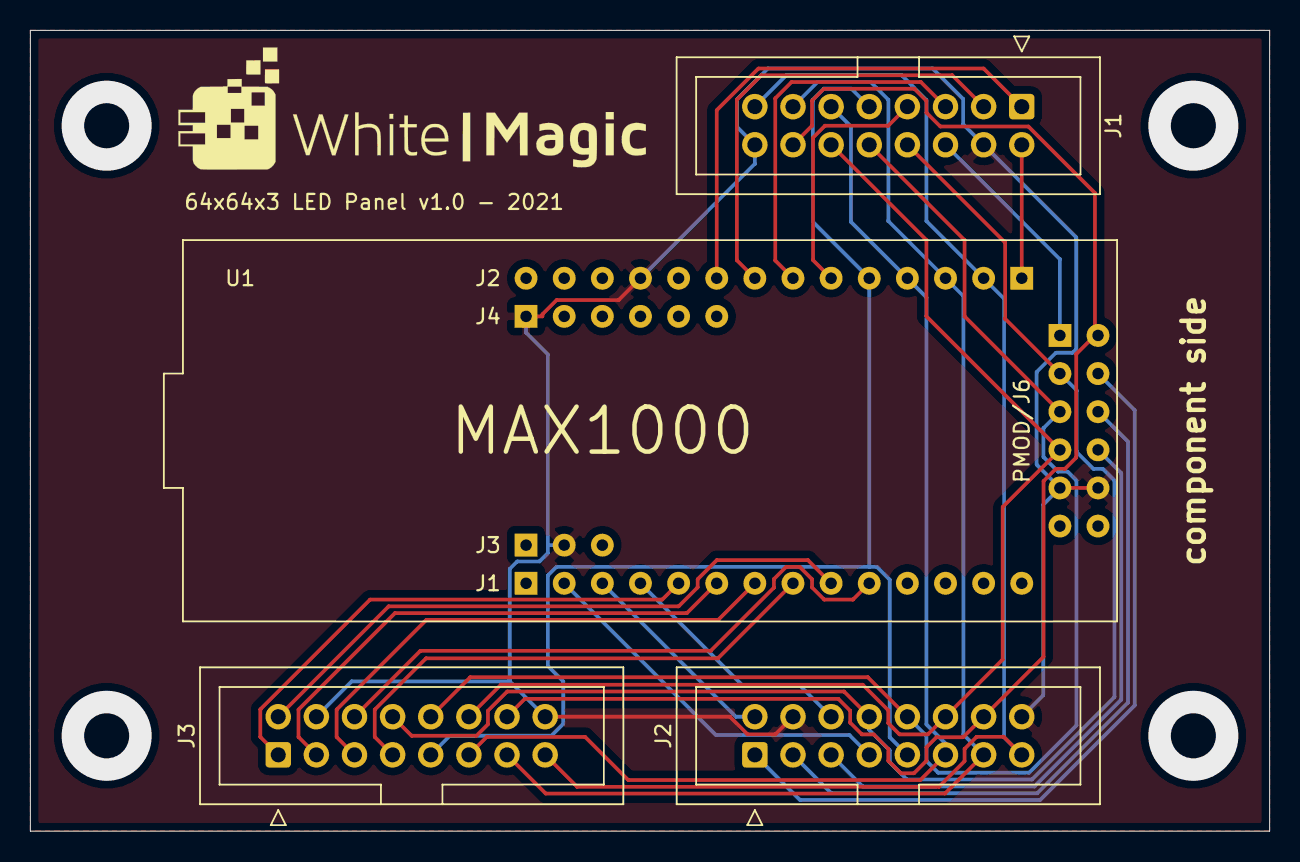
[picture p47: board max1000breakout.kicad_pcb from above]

Board: 2 copper layers, 82.6 x 53.3 mm, 5 parts (0 on the bottom side), 27 nets.

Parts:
J1, J2, J3: Conn_02x08_Odd_Even; IDC-Header_2x08_P2.54mm_Vertical
Ref**: Val**; whitemagic_logo
U1: MAX1000

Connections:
/gnd: J1.4, J1.16, J2.4, J2.16, J3.4, J3.16, U1.4, U1.33, U1.39, U1.42, U1.44
/m6: J1.1, U1.6
/m7: J1.3, U1.7
/m8: J1.5, U1.8
/m9: J1.7, U1.9
/m10: J1.9, J2.9, J3.9, U1.10
/m11: J1.11, J2.11, J3.11, U1.11
/m12: J1.13, J2.13, J3.13, U1.12
/m13: J1.15, J2.15, J3.15, U1.13
/m14: J1.2, U1.14
/m15: J1.6, U1.29
/m16: J1.8, J2.8, J3.8, U1.30
/m17: J1.10, J2.10, J3.10, U1.31
/m18: J1.12, J2.12, J3.12, U1.32
/m19: J1.14, J2.14, J3.14, U1.35
/m20: J2.1, U1.36
/m21: J2.3, U1.37
/m22: J2.5, U1.38
/m23: J2.7, U1.16
/m24: J2.2, U1.17
/m25: J2.6, U1.18
/m26: J3.1, U1.19
/m27: J3.3, U1.20
/m28: J3.5, U1.21
/m29: J3.7, U1.22
/m30: J3.2, U1.23
/m31: J3.6, U1.24

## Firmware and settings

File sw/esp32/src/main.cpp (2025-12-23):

#include <stdio.h>
#include <math.h>
#include <cstdlib>

#include <freertos/FreeRTOS.h>
#include <freertos/task.h>
#include <driver/gpio.h>
#include "esp_ota_ops.h"

#include "esp_chip_info.h"
#include "esp_flash.h"
#include "events.h"
#include "i2cwrapper.h"
#include "nvs.h"
#include "nvs_flash.h"
#include "spiwrapper.h"

#include "application.h"
#include "applicationrunner.h"
#include "appsettings.h"
#include "bitmap.h"
#include "color.h"
#include "diagnostic.h"
#include "ds3231.h"
#include "environment_weerlive.h"
#include "environment_openweather.h"
#include "fpgaconfigurator.h"
#include "graphics.h"
#include "ledpanel.h"
#include "setupui.h"
#include "timesyncer.h"
#include "userinput_keys.h"
#include "wificlient.h"

#define BUTTON_SET    GPIO_NUM_35
#define BUTTON_UP     GPIO_NUM_32
#define BUTTON_DOWN   GPIO_NUM_34
#define BUTTON_BOOT   GPIO_NUM_0

#define FPGA_SPI_CLK         GPIO_NUM_21
#define FPGA_SPI_MOSI        GPIO_NUM_25
#define FPGA_SPI_MISO        GPIO_NUM_22
#define FPGA_RESET           GPIO_NUM_19
#define I2C_SDA              GPIO_NUM_18
#define I2C_CLK              GPIO_NUM_5

void init_spiffs()
{
    esp_vfs_spiffs_conf_t spiffs_config = {
        .base_path = "/spiffs",
        .partition_label = nullptr,
        .max_files = 5,
        .format_if_mount_failed = false
    };
    esp_vfs_spiffs_register(&spiffs_config);
}

void initNVS()
{
    auto result = nvs_flash_init();
    if (result == ESP_ERR_NVS_NO_FREE_PAGES || result == ESP_ERR_NVS_NEW_VERSION_FOUND)
    {
        ESP_ERROR_CHECK(nvs_flash_erase());
        result = nvs_flash_init();
    }
    ESP_ERROR_CHECK(result);
}

void checkSwitchPreviousFirmware()
{
    gpio_set_direction(BUTTON_DOWN, GPIO_MODE_INPUT);
    gpio_set_pull_mode(BUTTON_DOWN, GPIO_PULLUP_ONLY);
    gpio_pullup_en(BUTTON_DOWN);
    gpio_set_direction(BUTTON_UP, GPIO_MODE_INPUT);
    gpio_set_pull_mode(BUTTON_UP, GPIO_PULLUP_ONLY);
    gpio_pullup_en(BUTTON_UP);
    if (gpio_get_level(BUTTON_DOWN) == 0 && gpio_get_level(BUTTON_UP) == 0)
    {
        printf("switching to previous partition\n");
        auto oldota = esp_ota_get_next_update_partition(nullptr);
        esp_ota_set_boot_partition(oldota);
        esp_ota_mark_app_valid_cancel_rollback();
        while (gpio_get_level(BUTTON_DOWN) == 0 && gpio_get_level(BUTTON_UP) == 0)
            ;
        esp_restart();
    }
}

extern "C" {

void app_main() 
{
    checkSwitchPreviousFirmware();
    printf("application starting, version=%s\n", Version::application().astxt());

    gpio_set_direction(FPGA_SPI_CLK, GPIO_MODE_OUTPUT);
    gpio_set_direction(FPGA_SPI_MOSI, GPIO_MODE_OUTPUT);
    gpio_set_direction(FPGA_SPI_MOSI, GPIO_MODE_INPUT);
    gpio_set_direction(BUTTON_SET, GPIO_MODE_INPUT);
    gpio_set_direction(BUTTON_UP, GPIO_MODE_INPUT);
    gpio_set_direction(BUTTON_DOWN, GPIO_MODE_INPUT);

    initNVS();
    init_spiffs();

    auto events = new Events();

    auto spi = new SpiWrapper(SPI2_HOST, FPGA_SPI_CLK, FPGA_SPI_MOSI, FPGA_SPI_MISO, 5400000, false);
    FpgaConfigurator FpgaConfig(spi, "/spiffs/ice40hx4k.bin", FPGA_RESET);
    FpgaConfig.configure();

    auto settings = new AppSettings("standalonepanel");    
    auto panel = new LedPanel(128, 64, *settings, *spi);

    auto graphics = new Graphics(panel->dx(), panel->dy());
    auto i2c = new I2CWrapper(I2C_NUM_0, I2C_CLK, I2C_SDA);
    i2c->start();
    auto rtc = new DS3231(i2c);
    auto system = new System(settings, rtc, events);
    auto userinput = new UserInputKeys(BUTTON_SET, BUTTON_UP, BUTTON_DOWN, BUTTON_BOOT, system);
    auto environmentWL = new EnvironmentWeerlive(system, *settings, events->allocate("weerlive"));
    auto environmentOW = new EnvironmentOpenWeather(system, *settings, events->allocate("openweather"));
    auto environment = new EnvironmentSelector(std::vector<EnvironmentBase*>{ environmentWL, environmentOW }, *settings);

    auto appdata = new ApplicationContext(*settings);

    auto appui = new Application(*appdata, *environment, *system, *userinput);
    auto configui = new ConfigurationUI(*appdata, *environment, *system, *userinput);
    auto otaui = new OTAUI(*appdata, *environment, *system, *userinput);
    auto setupui = new SetupUI(*appdata, *environment, *system, *userinput, *panel);
    auto apprunner = new ApplicationRunner(*appdata, *panel, *appui, *configui, *otaui, *setupui, *system, *graphics);
    auto timeupdater = new TimeSyncer(*rtc, *settings, events->allocate("timesync"));

    xTaskCreate([](void*arg) { for(;;) ((ApplicationRunner*)arg)->render();  }, "render", 60000, apprunner, 1, nullptr);
    xTaskCreate([](void*arg) { for(;;) ((ApplicationRunner*)arg)->display(); }, "display", 4000, apprunner, 1, nullptr);
    xTaskCreate([](void*arg) { for(;;) ((UserInputKeys*)arg)->update(); }, "userinput", 4000, userinput, 1, nullptr);

    printf("application initialized\n");
    Diagnostic::printmeminfo();

    timeupdater->update(true);     // force immediate update from RTC

    // use main thread for running periodic tasks.
    auto accept_current_firmware = otaui->current_firmware_needs_acceptance();
    for (;;)
    {
        events->wait(500);

        // established wifi forces weather update.
        if (system->wifiConnectedEvent()->wasSet() && system->wifiConnected())
        {
            environment->triggerUpdate();
            timeupdater->triggerUpdate();
        }

        if (environment->triggerUpdateEvent()->wasSet())
        {
            environment->update();
        }
        if (timeupdater->triggerUpdateEvent()->wasSet())
        {
            timeupdater->update(false); // ignore RTC when NTP is enabled
        }
        if (otaui->isUpdateAvailable())
        {
            apprunner->newVersionAvailable();
        }
        if (accept_current_firmware)
        {
            accept_current_firmware = false;
            otaui->accept_current_firmware();
        }
    }
}

}

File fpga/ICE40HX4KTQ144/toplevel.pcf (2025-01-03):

set_io i_clk12M 129
set_io i_spi_clk 70
set_io i_spi_sdi 68
set_io o_spi_sdo 67
set_io o_tst_led 7
set_io i_tst_button 143

set_io o_sram_cs 101
set_io o_sram_oe 56
set_io o_sram_wr 90

set_io io_sram_data[0] 99
set_io io_sram_data[1] 98
set_io io_sram_data[2] 97
set_io io_sram_data[3] 96
set_io io_sram_data[4] 95
set_io io_sram_data[5] 94
set_io io_sram_data[6] 93
set_io io_sram_data[7] 91
set_io io_sram_data[8] 43
set_io io_sram_data[9] 44
set_io io_sram_data[10] 45
set_io io_sram_data[11] 47

set_io o_sram_addr[0] 107
set_io o_sram_addr[1] 106
set_io o_sram_addr[2] 105
set_io o_sram_addr[3] 104
set_io o_sram_addr[4] 102
set_io o_sram_addr[5] 88
set_io o_sram_addr[6] 87
set_io o_sram_addr[7] 85
set_io o_sram_addr[8] 84
set_io o_sram_addr[9] 83
set_io o_sram_addr[10] 37
set_io o_sram_addr[11] 38
set_io o_sram_addr[12] 39
set_io o_sram_addr[13] 41
set_io o_sram_addr[14] 42
set_io o_sram_addr[15] 60
set_io o_sram_addr[16] 61
set_io o_sram_addr[17] 63

set_io o_dsp_clk 137
set_io o_dsp_latch 136
set_io o_dsp_oe_n 138

set_io o_dsp_addr[0] 130
set_io o_dsp_addr[1] 128
set_io o_dsp_addr[2] 135
set_io o_dsp_addr[3] 134
set_io o_dsp_addr[4] 125

set_io o_dsp_rgbs[0] 120 
set_io o_dsp_rgbs[1] 118 
set_io o_dsp_rgbs[2] 119 
set_io o_dsp_rgbs[3] 124 
set_io o_dsp_rgbs[4] 121 
set_io o_dsp_rgbs[5] 122 
set_io o_dsp_rgbs[6] 114 
set_io o_dsp_rgbs[7] 113 
set_io o_dsp_rgbs[8] 112 
set_io o_dsp_rgbs[9] 117
set_io o_dsp_rgbs[10] 116
set_io o_dsp_rgbs[11] 115 

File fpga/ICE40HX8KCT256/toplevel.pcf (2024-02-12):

# ##############################################################################

# iCEcube PCF

# Version:            2020.12.27943

# File Generated:     Jan 17 2024 20:29:36

# Family & Device:    iCE40HX8K

# Package:            CT256

# ##############################################################################


set_io i_clk100M J3
set_io i_reset_n K11
set_io i_uart_rx L11
set_io o_uart_tx T16
set_io o_led1 M12
set_io o_led2 R16

set_io o_sram_cs T6
set_io o_sram_oe L9
set_io o_sram_wr T7

set_io io_sram_data[0] T8
set_io io_sram_data[1] P7
set_io io_sram_data[2] N9
set_io io_sram_data[3] T9
set_io io_sram_data[4] M9
set_io io_sram_data[5] R9
set_io io_sram_data[6] K9
set_io io_sram_data[7] P9
set_io io_sram_data[8] R10
set_io io_sram_data[9] L10
set_io io_sram_data[10] P10
set_io io_sram_data[11] N10

set_io o_sram_addr[0] N6
set_io o_sram_addr[1] T1
set_io o_sram_addr[2] P4
set_io o_sram_addr[3] R2
set_io o_sram_addr[4] N5
set_io o_sram_addr[5] T2
set_io o_sram_addr[6] P5
set_io o_sram_addr[7] R3
set_io o_sram_addr[8] R5
set_io o_sram_addr[9] T3
set_io o_sram_addr[10] R4
set_io o_sram_addr[11] M7
set_io o_sram_addr[12] N7
set_io o_sram_addr[13] P6
set_io o_sram_addr[14] M8
set_io o_sram_addr[15] T5
set_io o_sram_addr[16] R6
set_io o_sram_addr[17] P8

set_io o_dsp_clk E3
set_io o_dsp_latch H5
set_io o_dsp_oe_n E2

set_io o_dsp_addr[0] D2
set_io o_dsp_addr[1] G5
set_io o_dsp_addr[2] D1
set_io o_dsp_addr[3] G4
set_io o_dsp_addr[4] F4

set_io o_dsp_rgbs[0] F5  # Blue1
set_io o_dsp_rgbs[1] B2  # Green1
set_io o_dsp_rgbs[2] E4  # Red1
set_io o_dsp_rgbs[3] C2  # Blue2
set_io o_dsp_rgbs[4] C1  # Green2
set_io o_dsp_rgbs[5] B1  # Red2

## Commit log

2021-07-18 version 1.0
    [max1000breakout.kicad_pcb, max1000breakout.sch]
2021-07-25 modified for 64x64x3 breakout board
2021-10-03 first step in scene switching
2023-04-02 merged sw fpga and pcb repos
    [max1000breakout.kicad_pcb, max1000breakout.sch]
2023-09-03 external documentation
    [iCE40PinoutHX8K.xlsx]
2023-12-30 cleaned up changed pinout (pcf) for easier mapping on IDC16 connector
2024-01-14 added uart receive with automatic bitrate detection
2024-02-12 added display/write to different screens
    [standalonepanel.kicad_pcb, standalonepanel.kicad_sch]
2024-02-18 preliminary clock working, a slightly too slow on 115200 baud Lut still does not seem to function properly when update via uart
2024-03-20 3D Models v23 all ok, not tested with PCB All electronics designed including PCB - untested
    [coverplate.3mf, coverplate.stl, freerouting.dsn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]
2024-04-16 electronics & PCB v1
    [standalonepanel-B_Cu.gbl, standalonepanel-B_Mask.gbs, standalonepanel-B_Paste.gbp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]
2024-05-15 fix schematic errors: - swapped TxD/RxD + resistor CH340 - corrected footprint of DS3231 (was too big) textual errors of U2 (C-variant 1.2V)
    [standalonepanel.kicad_pcb, standalonepanel.kicad_sch]
2024-05-15 more esp32 datasheets
2024-05-15 Added SPIFFS filesystem with FPGA binary and able to read it from code. remove old ESP32 sourcecode
    [partitions.csv]
2024-05-23 update vhdl to boot correctly, start of spi interface
    [toplevel.pcf]
2024-06-19 stable working version of update display memory from ESP32
2024-06-23 corrected connections of blue/red removed variables by signals in vhdl that were not used just locally. fixed reset behavior of spi receiver made start with C++ bitmap and ledpanel class
    [main.cpp, toplevel.pcf]
2024-07-02 changed I2C address of MPU6050 from 0x68 to 0x69 to remove conflict with DS3231
    [standalonepanel.kicad_pcb, standalonepanel.kicad_sch]
2024-07-03 added SDA and SCL pullup resistors swapped teh SDA and SCL lines for DS3231
    [standalonepanel.kicad_pcb, standalonepanel.kicad_sch]
2024-07-03 working interactions with DS3231 and MPU6050 MPU6050 still unstable readings, maybe hardware (pullup or soldering was too hot)
    [main.cpp]
2024-08-18 lots of esp32 code changes, started with final application
2024-08-21 added date/time display
    [partitions.csv]
2024-09-11 added clamps for attaching panel to wooden frame (this clamps turned out a little too high though)
    [frame-clamp.3mf, frame-clamp.stl, standalonepanel.kicad_sch]
2024-09-15 fixed json parse bug and various other improvements
    [application.cpp]
2024-09-27 Schematic v2 PCB version v2 send for production
    [standalonepanel-B_Cu.gbl, standalonepanel-B_Mask.gbs, standalonepanel-B_Paste.gbp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]
2024-10-03 fixed month-1 bug, removed potential memoryleak
    [main.cpp]
2024-11-06 added time part of configuration UI, added wifi scanning/connecting.
    [configurationui.h]
2024-11-10 added DST flag, addded nvs to store settings, some translations
    [configurationui.h]
2024-11-10 fixed some bugs with DST, some configuration refactors
    [configurationui.h]
2024-11-10 working version of text editing, needs some more animations (smooth scrolling) and better delete behavior when deleting halfway.
    [configurationui.h]
2024-11-14 added scrolling for long config values, fading in between different screens, many refactors in structure,
    [configurationui.h]
2024-11-14 added repeat of config selection
    [configurationui.h, standalonepanel.kicad_pcb, standalonepanel.kicad_sch]
2024-11-17 many small fixes, sed SPIRAM to get all working due to out of memory with network calls, this did slow down rendering to 14fps
    [configurationui.h]
2024-12-08 removed old max1000 code
    [max1000breakout.kicad_pcb, max1000breakout.sch]
2024-12-08 v3 of electronics
    [standalonepanel.kicad_pcb, standalonepanel.kicad_sch]
2024-12-10 some new SDK changes switch back to 16MB due to other esp module
2024-12-10 added PCB v3 corner mechanical element
    [panel-corner6.3mf, panel-corner6.stl]
2024-12-12 swapped notion of panel 1 & 2
    [toplevel.pcf]
2024-12-12 added option to flip display (rotate 180) to get USB port on other side. added fading of weather info when not available.
    [configurationui.h]
2024-12-12 updated Fusion 3d designs
    [panel-corner-link.3mf, panel-corner-link.stl, panel-corner-link3.3mf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]
2024-12-16 add single panel display, refactor graphics/bitmap to support views
    [configurationui.h]
2024-12-17 fixed clipping for origin(0,0) views and some bugfixes
    [application.cpp, main.cpp]
2024-12-27 changes for onepanel application, fixed fonts and numerous bugfixes and improvements
    [configurationui.h]
2025-01-03 integrated use of NTP server & timezones setting change callback various bug fixes and improvements full support for the openweather api refactored drawing of weather images
    [configurationui.h, partitions.csv]
2025-01-03 initdata now clears display attempt to inhibit startup artifacts on display correctly connect fpga led on PCB
    [toplevel.pcf]
2025-01-05 added OTA add version
    [configurationui.h, partitions.csv]
2025-01-13 removed kicad intermediate directory
    [freerouting.dsn, standalonepanel-2.kicad_sch, standalonepanel.csv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]
2025-01-13 mechanical update
    [coverplate-lip.3mf, coverplate-lip.stl, coverplate-no-lip.stl]
2025-02-15 added flip option of keys (due to new type2 panel)
    [configurationui.h]
2025-02-16 added setup screen (press boot 3sec) to setup different panel layouts.
    [configurationui.h]
2025-03-09 many changes, support for vertical panel, added sunrise/set graphics
    [configurationui.h]
2025-03-26 added automatic periodic software update checks
    [configurationui.h]
2025-07-17 updated mechanics files
    [coverplate-lip.3mf, coverplate-lip.stl, coverplate-no-lip.stl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]
2025-10-12 fixed graphics clipping added OTA fastpoll revert after 3H idle cleanup
    [main.cpp]
2026-02-11 cleanup kicad files and added overview documentation
    [standalonepanel-2.kicad_sch, standalonepanel.csv, standalonepanel.kicad_pcb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]
